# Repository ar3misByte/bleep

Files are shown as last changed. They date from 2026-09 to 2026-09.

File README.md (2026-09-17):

# Bleep

Worker safety monitoring for underground mine sites — a worker-worn ESP32 detects falls, prolonged inactivity, and environmental/vitals hazards, and a live dashboard surfaces alerts to site supervisors.

## Sensors on the worker unit

- **MPU6050** — 6-axis IMU: fall & impact detection, prolonged-inactivity detection
- **DHT11** — ambient temperature & humidity (heat-stress alerting)
- **BMP180** — barometric pressure
- **MQ-135** — toxic/air-quality gas
- **MQ-4** — combustible gas (methane/LPG) — the most safety-critical reading underground
- **MAX30102** — heart rate & an approximate SpO2 estimate
- **Soil moisture sensor** — floor-level water-ingress/flooding proxy
- **Physical SOS button** — manual worker-triggered distress

Every one of these feeds the same latched-alarm path (LED + buzzer on, dashboard shows a live DISTRESS event, cleared by pressing the SOS button again to acknowledge) — see [`dashboard_features.md`](./dashboard_features.md) for the full breakdown and current threshold values.

## Dashboard

[`index.html`](./index.html) is the dashboard — open it directly in a browser, or serve the repo with GitHub Pages. It's built with plain HTML/CSS/JS (no build step).

- **Worker roster cards** show live per-worker data wired to the real ESP32 hardware: motion energy, RSSI, temperature/humidity/pressure, gas readings, heart rate/SpO2, and soil moisture — the last four colored red once they cross the same danger threshold the firmware alarms on.
- **Event log** and **alert banner** cover every distress source (fall, SOS, inactivity, heat, gas, heart rate, SpO2, water ingress) generically, since `riskState`/`hazardType` are open strings, not a fixed enum.

See [`dashboard_features.md`](./dashboard_features.md) for the feature-by-feature status tracker (`LIVE` / `WIRED` / `PLANNED`) that the dashboard is kept in sync with.

### The three dashboard files

There are three HTML dashboards in this repo, not one — they're different snapshots, not alternatives to pick between at random:

- [`index.html`](./index.html) — the relay-server-connected dashboard described above. This is the one you actually serve from `server/app.py` to see real hardware.
- [`sensora_watch.html`](./sensora_watch.html) — the standalone, no-server "Sensora Watch" command dashboard (seven tabs: Overview, Workers, Alerts, Vitals & Gas, Mine Map, Reports, Admin) published as a Claude Artifact; see [`dashboard_features.md`](./dashboard_features.md) for what it does. Runs entirely on simulated data — open it directly in a browser.
- [`bleep_watch.html`](./bleep_watch.html) — the same command dashboard, rebranded ("Bleep Command" instead of "Sensora Watch") and with one addition: a **Live Data** tab that polls a wall node's own `/api/workers` endpoint directly (see "Second node pair" below) and shows the raw, unprocessed feed, so it's obvious where real hardware readings appear instead of them blending in with simulated worker cards. Configure the wall node address under Admin → Live Hardware.

## Connecting real hardware

The dashboard talks to hardware through a small relay server, not directly — the wall node is an HTTP **client**, the dashboard machine runs the HTTP **server**.

```
[worker wearable] --ESP-NOW--> [wall node ESP32] --WiFi/HTTP POST--> [server/app.py] --serves--> [index.html in your browser]
```

0. **Install the worker's Arduino libraries** (Library Manager): `Adafruit MPU6050`, `Adafruit Unified Sensor`, `DHT sensor library` (Adafruit), `Adafruit BMP085 Library` (covers BMP180), and `SparkFun MAX3010x Pulse and Proximity Sensor Library` (provides `MAX30105.h` and `heartRate.h`, used for the MAX30102). MQ-135, MQ-4, and the soil moisture sensor are plain `analogRead()` — no library needed.
1. **Put the wall node and your dashboard machine on the same WiFi network**, and find your machine's local IP (`ipconfig` on Windows, look for the WiFi adapter's IPv4 address — e.g. `192.168.1.50`).
2. **Edit [`firmware/wall_node.ino`](./firmware/wall_node.ino)**: set `WIFI_SSID`, `WIFI_PASSWORD`, and `DASHBOARD_URL` (`http://<your-ip>:5000/api/telemetry`) at the top, then flash it to the wall node's ESP32. It receives `WorkerPacket` structs over ESP-NOW from the wearable and forwards them as the telemetry JSON described in [`wifi_json_protocol.md`](./wifi_json_protocol.md).
3. **Run the relay server**:
   ```bash
   pip install -r server/requirements.txt
   python server/app.py
   ```
4. **Open the dashboard from the server, not the static file**: go to `http://<your-ip>:5000/` in a browser (on the same machine or anywhere else on the LAN). The page polls `/api/workers` and `/api/events` every 2 seconds — as soon as the wall node sends its first message, the page switches out of demo mode automatically: the worker roster, alert banner, and event log start showing real data, and the "Demo & Testing Controls" panel disables itself.

**Don't have wearable hardware yet?** Flash [`firmware/wearable_fall_simulator.ino`](./firmware/wearable_fall_simulator.ino) to a second ESP32 instead — it stands in for the wearable, sending STATUS packets every 2s and a simulated fall roughly every 45s (auto-recovering 15s later), so you can test the wall node → server → dashboard pipeline with no accelerometer involved.

**Why not just open `index.html` directly, or use the GitHub Pages copy?** Browsers block a page from fetching a plain-`http://` endpoint when the page itself was loaded over `https://` (GitHub Pages) or as a bare local file with no server behind it — the fetches to `/api/workers` fail silently and the page just stays in demo mode. Serving `index.html` from `server/app.py` (step 4) puts the page and the API on the same origin, which sidesteps this entirely. The hosted GitHub Pages copy is fine for showing the design, but it will never show live hardware data.

## Second node pair — tinyML anomaly detection ([`firmware/wall_n/`](./firmware/wall_n/), [`firmware/worker_n/`](./firmware/worker_n/))

[`firmware/wall_node.ino`](./firmware/wall_node.ino) and [`firmware/worker_node.ino`](./firmware/worker_node.ino) are left untouched. `wall_n.ino` and `worker_n.ino` are a **second, independent worker/wall pair** — not a replacement — that adds two things:

- **Its own local sensors on the wall node** — an MPU6050, BMP180, and DHT11 for room/wall-mounted environmental readings, plus an HC-SR04 ultrasonic sensor for distance/proximity (door, hazard boundary, or clearance sensing). See the pin map at the top of [`wall_n.ino`](./firmware/wall_n/wall_n.ino).
- **A tinyML anomaly-detection model on the worker node**, replacing hand-picked hazard thresholds with a small trained autoencoder (9 → 6 → 9) baked into `tinyml_model.h`. The model learns what a *normal* combination of the nine worker sensor readings looks like and flags a worker anomalous when the network can no longer reconstruct their current readings accurately — this naturally accounts for cross-sensor correlations (e.g. "high heart rate is only normal alongside high motion energy") that independent static thresholds can't express. Inference is plain float matrix math on-device, no TensorFlow Lite Micro runtime required.

`worker_n.ino`'s fall-detection and alarm logic is ported unchanged from a hand-tested standalone prototype — see the comment block at the top of [`worker_n.ino`](./firmware/worker_n/worker_n.ino) for exactly what carried over and what was intentionally dropped (e.g. there is no acknowledge button; the alarm stays latched until reset).

### Retraining the model ([`ml/train_tinyml_model.py`](./ml/train_tinyml_model.py))

`tinyml_model.h` (in both `firmware/wall_n/` and `firmware/worker_n/` — same generated file, kept in sync) is generated by `ml/train_tinyml_model.py`. There is no logged real-world sensor history for this project yet, so the script currently trains on **synthetic data** sampled from the plausible "normal" ranges already documented as static thresholds in `worker_node.ino` (`TEMP_DANGER_C`, `MQ135_DANGER_RAW`, `HR_DANGER_*`, etc.) plus typical sensor datasheet ranges. Treat this as a placeholder, not a substitute for real data — re-run the script against logged real sensor values as soon as they exist so the model learns the actual normal envelope for your site and workers. Run with `python ml/train_tinyml_model.py`; it has no dependency on the rest of the codebase beyond regenerating the header. See [`TinyML_Model_and_Datasets.md`](./TinyML_Model_and_Datasets.md) for the full writeup of the model architecture, training pipeline, and exactly how the synthetic dataset is built.

## PCB reference designs ([`kicad/`](./kicad/))

Vendored third-party reference material, not designs authored for this project — currently just Adafruit's own open-source [MPU6050 breakout PCB](https://www.adafruit.com/product/3886) (EagleCAD schematic/board files, CC BY-SA per Adafruit's license). Kept here as a starting reference for anyone laying out a custom PCB for the worker unit instead of prototyping on a breadboard.

## Design source

The `Main.dc.html` + `canvas.json` pair is the source for the same dashboard as an editable [Claude Design](https://claude.ai/design) canvas.

## Project docs

- [`Sensora_Hardware_Firmware_Spec.md`](./Sensora_Hardware_Firmware_Spec.md)
- [`wifi_json_protocol.md`](./wifi_json_protocol.md)
- [`sensora_telemetry.schema.json`](./sensora_telemetry.schema.json)
- [`sensora_architecture.md`](./sensora_architecture.md)
- [`Sensora_Feature_Build_Checklist.docx`](./Sensora_Feature_Build_Checklist.docx)
- [`Sensora_Novelty_Analysis.docx`](./Sensora_Novelty_Analysis.docx)
- [`Problem_Statement_SENSORA.pdf`](./Problem_Statement_SENSORA.pdf)

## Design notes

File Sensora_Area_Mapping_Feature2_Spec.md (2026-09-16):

# Feature 2 — Area Mapping with MPU6050 + HC-SR04 (gyro-swept ultrasonic scan)

**Supersedes the "proximity snapshot" scope-down in `dashboard-features.md` / `feature-build-checklist.md`.** Those docs parked full mapping because a continuous mechanical sweep needs a servo you may not have. This spec instead uses the **worker's own arm/body motion as the sweep mechanism** — MPU6050 gyro-integrated yaw tells you the angle, HC-SR04 tells you the distance at that angle, and the firmware fuses the two into a 2D point cloud. No servo required. This is genuinely buildable without new hardware if you already have both sensors, and it turns Feature 2 from a snapshot into an actual on-screen room/tunnel outline.

---

## 0. The core idea

A single ultrasonic sensor only measures distance along one ray. To get a *shape*, you need distance samples across a range of angles. Instead of motorizing the sensor, you have the person holding/wearing the unit **sweep it by hand** (like panning a flashlight across a room) while the firmware:

1. tracks the sensor's heading in real time by integrating the MPU6050's gyro Z-axis,
2. pings the HC-SR04 repeatedly during the sweep,
3. pairs each distance reading with the heading at that instant,
4. converts each (angle, distance) pair into an (x, y) point relative to the sweep's starting position,
5. streams the resulting point set to the dashboard, which draws it as a 2D outline.

This is a **relative, single-sweep scan**, not persistent SLAM — it answers "what does the space around the worker look like right now," which is exactly what Feature 2's brief was aiting at, and it's a much stronger demo than a single-ray snapshot.

---

## 1. Hardware (no new parts beyond what's already in the BOM)

| Component | Already in BOM? | Role here |
|---|---|---|
| ESP32 | Yes (worker or a dedicated scan node) | Compute, drives the sweep logic |
| MPU6050 | Yes (`hardware-firmware-spec.md` §1.1 — I²C, addr `0x68`) | Gyro Z-axis → yaw integration during the sweep |
| HC-SR04 | Yes, per `architecture-plan.md` §3.3 (used there for water level; you need a second unit, or repurpose logic — ultrasonic modules are ~$1–2, worth having two) | Distance ray at the current heading |

**Wiring (HC-SR04, in addition to the existing MPU6050 I²C bus from `hardware-firmware-spec.md` §1.3):**

| Signal | Suggested GPIO | Notes |
|---|---|---|
| TRIG | GPIO32 | Output, 10µs HIGH pulse to fire a ping |
| ECHO | GPIO33 | Input — **use a voltage divider (1kΩ/2kΩ) if your HC-SR04 is 5V-logic**, ESP32 GPIOs are not 5V tolerant |

Both GPIO32/33 are free ADC1-adjacent pins not used elsewhere in the worker pin map (§1.3 of `hardware-firmware-spec.md` uses 21/22/34/25/27/26/4/35) — confirm against your actual board before wiring.

If you're mounting this on a **separate dedicated scan unit** rather than the worker's own helmet (recommended — see §5), the same two sensors plus an ESP32 is the entire BOM; it doesn't need the gas/temp sensors or the buzzer.

---

## 2. Firmware: the sweep algorithm

### 2.1 Trigger a scan

Add a dedicated button (or repurpose a long-press on the existing SOS button if you want zero new parts) to start/stop a scan session. Keep sessions **short — 5 to 8 seconds** for a single sweep; this bounds gyro drift (§2.2) and keeps the data volume manageable over ESP-NOW.

```
on scanButtonPressed():
    if not scanning:
        startScan()   // zero the yaw integrator, clear the point buffer, set scanning = true
    else:
        endScan()     // stop sampling, package and send the accumulated points
```

### 2.2 Yaw tracking (gyro integration, with the drift caveat already flagged in your own docs)

This reuses exactly the pattern `architecture-plan.md` names for the (cut) GPS-replacement `yawDeg` field, and the complementary-filter idea already used for tilt in `hardware-firmware-spec.md` §7.3:

```cpp
// called every IMU sample (~50 Hz, non-blocking, per the main-loop discipline in §9 of the firmware spec)
void updateYaw(float gyroZ_degPerSec, float dt_s) {
    yawDeg += gyroZ_degPerSec * dt_s;
    // no magnetometer on hand -> no absolute heading correction.
    // Over a short (5-8s) sweep the drift is small enough to be visually
    // acceptable for a hackathon demo; DO NOT trust this for anything
    // longer-running or safety-critical. Label it as such on the dashboard
    // (see §4) exactly the way GPS-cut and simulated-data fields are labeled
    // elsewhere in this project.
}
```

Zero `yawDeg` at `startScan()` so every sweep is self-consistent even though absolute compass heading isn't available.

### 2.3 Ultrasonic sampling

```cpp
float pingDistanceCm() {
    digitalWrite(TRIG_PIN, LOW);  delayMicroseconds(2);
    digitalWrite(TRIG_PIN, HIGH); delayMicroseconds(10);
    digitalWrite(TRIG_PIN, LOW);
    unsigned long durationUs = pulseIn(ECHO_PIN, HIGH, 30000UL); // 30ms timeout ~= 5m range cap
    if (durationUs == 0) return -1;          // no echo / out of range -> discard sample
    float distanceCm = durationUs / 58.0f;
    if (distanceCm < 2 || distanceCm > 400) return -1;  // HC-SR04's real usable range
    return distanceCm;
}
```

**Important non-blocking note:** `pulseIn` blocks for up to its timeout (here 30ms). That's short enough not to meaningfully stall the mesh/heartbeat loop, but don't call it more often than every ~60ms (the HC-SR04 needs settling time between pings per its datasheet, matching the `MQ7`-style "don't take a shortcut on sensor timing" instruction already in `hardware-firmware-spec.md` §8) — schedule it the same way as the other periodic tasks in §9's `loop()` pattern:

```cpp
if (scanning && (now - lastPing >= SCAN_PING_INTERVAL_MS)) {   // config.h, default 100ms
    float d = pingDistanceCm();
    if (d > 0) {
        recordScanPoint(yawDeg, d);   // buffer the (angle, distance) pair
    }
    lastPing = now;
}
```

At 100ms per ping over a 6-second sweep, that's up to ~60 points — plenty for a recognizable outline, and small enough to fit in the packet budget below.

### 2.4 Polar → Cartesian conversion

Do this conversion **on the worker/scan node**, not the backend — it's cheap, and it means the packet carries directly plottable coordinates:

```cpp
struct ScanPoint { int16_t x_cm; int16_t y_cm; };  // fixed-point, matches the packet.h convention

ScanPoint toCartesian(float yawDeg, float distanceCm) {
    float rad = yawDeg * (PI / 180.0f);
    return { (int16_t)(distanceCm * cosf(rad)), (int16_t)(distanceCm * sinf(rad)) };
}
```

---

## 3. Wire format: extend `packet.h`, don't invent a parallel protocol

Per the note already in `dashboard-features.md` ("this is meant to extend the existing DISTRESS payload... not create a parallel envelope") and the versioned-payload pattern in `hardware-firmware-spec.md` §4, add a new `MsgType` rather than a new protocol:

```c
// packet.h additions
MSG_SCAN_CHUNK = 5,   // one chunk of a multi-packet area scan

typedef struct __attribute__((packed)) {
    uint8_t  scanId;        // increments per scan session, lets the gateway group chunks
    uint8_t  chunkIndex;    // 0-based
    uint8_t  chunkCount;    // total chunks in this scan, so the gateway knows when it's complete
    uint8_t  pointCount;    // points in THIS chunk
    int16_t  points[10][2]; // up to 10 (x_cm, y_cm) pairs per chunk
} ScanChunkPayload;         // 10*4 + 4 = 44 bytes, comfortably inside the 64-byte payload[] and the 250-byte ESP-NOW cap
```

A 60-point sweep needs 6 chunks of 10 points each — trivial over ESP-NOW, and it reuses the exact same anchor-relay/dedup path (§5, §6.2 of `hardware-firmware-spec.md`) every other packet type already uses, so nothing new is needed in the mesh layer.

**Gateway side:** buffer chunks by `scanId` as they arrive, and once `chunkCount` chunks are seen (or a timeout elapses — don't block waiting forever on a lost packet), assemble the full point list and emit one JSON message to the backend:

```json
{"msgType":"AREA_SCAN","srcId":103,"scanId":7,"originAnchorId":2,
 "points":[[120,45],[118,60],[95,88], ...], "pointCount":58, "rxAtMs":183820113}
```

---

## 4. Backend + dashboard

**Backend (`architecture-plan.md` §5 pattern):**
- New table: `area_scans(id, worker_id, ts, origin_anchor_id, points_json, is_partial)`.
- New MQTT topic: `sensora/scan/{nodeId}`.
- New WS diff type pushed to the dashboard when a scan completes.

**Dashboard — new panel, e.g. `AreaScanPanel`, following the design tokens already fixed in `dashboard-features.md`:**
- A simple 2D scatter/polygon plot (SVG, no charting library needed for point-count this small — same "hand-laid-out SVG beats a heavy graph library" reasoning already used for `NetworkTopology` in `architecture-plan.md` §6).
- Plot each point at `(x_cm, y_cm)` relative to a centered origin marker representing the worker.
- Connect consecutive points with a thin line in sweep order to suggest a wall outline (don't force a closed polygon — a partial sweep is an open arc, and closing it would misrepresent the room).
- **Label it clearly**, matching the project's existing honesty pattern (`SIMULATED DATA` flag, `SIMULATED MODEL` tag): something like **"Relative scan — gyro-only heading, may drift over the sweep"** near the panel, exactly the same treatment already used for the cut GPS/`yawDeg` field.
- If you also have the RSSI-based coarse worker position (`hardware-firmware-spec.md` §6.3) wired into the dashboard, you can offset the scan's origin to that estimated position on the main topology view — a nice-to-have, not required for the panel to be useful on its own.

---

## 5. Practical recommendation for the demo

Two ways to run this, pick based on time left:

1. **Handheld dedicated scan unit (recommended):** a second ESP32 + MPU6050 + HC-SR04 on a small breadboard/enclosure, separate from the worker's helmet. Someone holds it and slowly pans it in an arc in front of a judge-visible obstacle (a box, a chair leg) while pressing the scan button. This is the safest to rehearse because it's a standalone prop, not entangled with the worker's own fall/SOS firmware.
2. **Bundled into the worker node:** reuse the worker's existing MPU6050, add the HC-SR04, and trigger a scan either manually (extra button) or automatically on a DISTRESS event (the original intent noted in `dashboard-features.md`: "extend the existing DISTRESS payload"). More impressive narratively ("the system automatically scans the area around a fallen worker") but higher integration risk since it shares firmware/timing with the safety-critical path — only do this after option 1 works standalone, and don't let it block Feature 1.

Either way, rehearse the actual sweeping motion a few times before the demo — a jerky or too-fast sweep undersamples badly and produces a noisy scatter instead of a recognizable outline. A slow, steady ~90–180° arc over 5–8 seconds gives the cleanest result.

---

## 6. What to say if a judge asks about accuracy

> "This is a relative scan, not absolute mapping — the heading comes from gyro integration with no magnetometer, so it drifts over time. We bound that by keeping each sweep short, a few seconds, and treating each scan as a fresh, self-contained snapshot rather than accumulating drift over a long session. It's the same honesty pattern we use elsewhere in the project — labeled clearly on the dashboard rather than presented as more precise than it is."

This is consistent with, and reuses, the exact justification style already used for the cut GPS feature and the simulated flood model elsewhere in the project docs.

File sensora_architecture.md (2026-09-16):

# Sensora — System Architecture Plan

**Project:** Intelligent Worker Safety & Resilient Emergency Response System
**Prepared:** 15 Sep 2026 · Assumptions: 36–48h hackathon, 4–6 person team with role specialization, a few ESP32 boards + basic sensors already on hand (rest sourced/substituted below)
**Status:** Planning document — update as decisions change during the build

---

## 0. How to read this document

This is the architecture the team should build against, plus the reasoning behind each call and the places it's likely to break. Section 12 ("What a judge will challenge") is deliberately unflattering — read it before you pitch, not after a judge asks.

Everything below is scoped to **one coherent narrative**: an edge device assesses risk locally, a resilient mesh carries that risk assessment even as nodes die, and a command dashboard makes the whole chain visible in one glance. Every component earns its place by serving one of the five required demos. Nothing else gets built first.

---

## 1. System Overview

```
                         ┌───────────────────────────┐
                         │   COMMAND DASHBOARD (React) │
                         │  WebSocket live feed + REST │
                         └──────────────┬───────────────┘
                                        │ WS / HTTP
                         ┌──────────────┴───────────────┐
                         │   BACKEND (FastAPI + MQTT)    │
                         │  risk fusion · DB · APIs      │
                         └──────────────┬───────────────┘
                                        │ MQTT (paho)
                    ┌───────────────────┼────────────────────┐
                    │                                        │
         ┌──────────┴──────────┐                  ┌──────────┴──────────┐
         │  SCENARIO SIMULATOR  │                  │   GATEWAY NODE (ESP32) │
         │ (flood/scale/failure)│                  │  ESP-NOW ↔ USB-Serial │
         └───────────────────────┘                  └──────────┬──────────┘
                                                                │ ESP-NOW (2.4GHz)
                                        ┌───────────────────────┼───────────────────────┐
                                        │                       │                       │
                                 ┌──────┴──────┐        ┌───────┴──────┐        ┌───────┴──────┐
                                 │ HELMET NODE  │        │  RELAY NODE   │        │  ENV/FLOOD NODE│
                                 │ temp/gas/IMU │  ◄──►  │ (no sensors,  │  ◄──►  │ water level +  │
                                 │ /SOS/buzzer  │  mesh  │  forwards only)│        │ rainfall input │
                                 └──────────────┘        └───────────────┘        └────────────────┘
```

Two things make this "one system" instead of five demos glued together:

1. **Every physical node speaks the same packet format and joins the same mesh**, whether it's a helmet, a bare relay, or the flood sensor. The flood node's CRITICAL alert travels through exactly the same routing/failover logic as a worker's SOS.
2. **Real and simulated data enter the backend through the identical path** (MQTT topics). The flood scenario, a 14-worker site, and a mid-transmission node failure are all just different publishers on the same bus — this is the strongest architectural point to make to judges, because it proves the pipeline rather than the props.

---

## 2. Communication Layer — the central engineering decision

This is the feature judges will probe hardest, so the comparison has to be real, not decorative.

| | **ESP-NOW (custom mesh)** | **WiFi Mesh (painlessMesh)** | **LoRa (point-to-point / Meshtastic)** | **BLE / BLE Mesh** |
|---|---|---|---|---|
| Range (indoor, obstructed) | ~15–40m | ~15–40m | 500m–several km | ~5–15m |
| Throughput | Low, small packets (≤250B) | Higher (TCP over WiFi) | Very low (kbps) | Low |
| Power draw | Low–medium | Medium–high (WiFi radio stays up) | Very low (duty-cycled) | Low |
| Native multi-hop | No — you write it | Yes (library handles it) | No — point-to-multipoint only, mesh needs extra firmware/protocol | Only with BLE Mesh spec (complex) |
| Hardware cost/node | ESP32 only (~$4–6) | ESP32 only | ESP32 + LoRa module (~$8–15 extra) + antenna | ESP32 only |
| Implementation complexity | Medium (you own the routing logic, but that's also full control) | Low–medium (library does self-healing) | High (new radio stack, range testing, antenna tuning) | High for real mesh |
| **Demo control** (can you force a failure/reroute exactly on cue?) | **High** — deterministic, you wrote it | Medium — library's internal healing timing is a black box | Low in the time available | N/A here |
| Fit for "break a node → judges watch it reroute" | **Best** | Good, less predictable | Would need too much new firmware to trust live | Not viable in this window |

**Recommendation: ESP-NOW as the radio, with a small custom application-layer routing protocol on top.**

Why not the "better" options:
- **WiFi mesh (painlessMesh)** is a legitimate alternative and less code to write, but you're trading control for convenience — its self-healing timing isn't yours to tune, which is risky when the entire Demo 3 depends on the reroute happening within a judge's attention span. If your team already knows painlessMesh well, it's an acceptable swap; otherwise don't learn a new library and a new protocol in the same 48 hours.
- **LoRa/Meshtastic** is the "sexiest" answer and genuinely fits a disaster narrative better (km-scale range), but it adds a second hardware type, an unfamiliar stack, and antenna/range testing you won't have time to debug if it goes wrong the night before. Flag it explicitly to the team and judges as **"the deployment-scale answer, out of scope for this prototype"** — that's an honest, technically credible statement, not a cop-out.
- **BLE mesh** is out — short range and the mesh spec is too heavy to implement correctly in this window.

### 2.1 Routing protocol ("SensoraMesh" — hackathon-scoped, hybrid)

This mirrors the idea behind Collection Tree Protocol (a well-known wireless-sensor-network pattern) for normal traffic, plus **flooding for anything safety-critical**, because flooding is trivially self-healing — it doesn't depend on any single path being correct, which is exactly the property you want on stage.

- Every node broadcasts a `HEARTBEAT` every 2–3s: `{nodeID, role, hopCountToGateway, battery, seq}`.
- Each node keeps a small neighbor table (`neighborID, RSSI, lastSeen, theirHopCount`) and computes `myHopCount = min(neighbor hopCount) + 1`, picking the neighbor with the lowest hop count (tie-break: strongest RSSI) as `bestNextHop`. This is a simple distance-vector/gradient routing toward the gateway.
- **Failure detection:** if no heartbeat from the current `bestNextHop` for 3 missed intervals (~9s), mark it stale and recompute from the remaining table. This 9s window is your reroute demo's visible "thinking" pause — don't try to make it instant, a visible-but-quick recovery actually reads better to judges than something so fast it looks scripted.
- **Normal telemetry** (NORMAL/WARNING state, low priority): unicast hop-by-hop via `bestNextHop`. Cheap, low airtime.
- **Emergency traffic** (CRITICAL/SOS, priority=1): **constrained flood** — broadcast to all neighbors, each relay forwards once (dedup cache keyed by `{srcID, seq}`, TTL-expired after a few seconds), hop-limited (e.g. TTL=8). This guarantees delivery via multiple simultaneous paths without waiting for route recomputation — the actual mechanism behind Demo 3.
- Gateway node bridges the mesh to the backend over **USB serial** (not WiFi) — this keeps the last hop deterministic during the demo (no dependency on venue WiFi/hotspot flakiness). The mesh itself is what's "resilient"; the laptop tether is a deliberate, disclosed simplification.

**If a judge says "isn't flooding just cheating instead of real routing?"** — answer: for safety-critical low-node-count networks, controlled flooding (TTL + dedup) is a legitimate, widely-used resilience pattern (it's the reliability mechanism behind Bluetooth Mesh and many disaster-relief mesh designs), traded deliberately against airtime efficiency. You're using the efficient path (distance-vector) for routine data and the robust path (flood) only for the traffic where guaranteed delivery matters more than efficiency — that's the "priority-aware" differentiator, not an accident.

### 2.2 Packet format

Fixed binary header to stay inside ESP-NOW's ~250-byte payload:

```
byte 0    : version
byte 1    : msgType        (0=HEARTBEAT, 1=TELEMETRY, 2=EMERGENCY, 3=ENV, 4=ACK)
byte 2    : srcID          (1-byte node address, fine for a demo-scale network)
bytes 3-4 : seq            (uint16, per-source sequence number — used for dedup + replay rejection)
byte 5    : ttl            (hop limit, decremented per forward)
byte 6    : hopCount       (hops traveled so far, for routing table math)
byte 7    : priority       (0=normal, 1=emergency)
byte 8    : payloadLen
bytes 9-9+len : payload    (type-specific, see below)
last 2 bytes : CRC16       (integrity check)
```

- `TELEMETRY` payload: `tempC (int16), gasRaw (uint16), motionFlag (uint8), batteryPct (uint8)`
- `EMERGENCY` payload: `hazardType (uint8 enum), severity (uint8 enum), tempC, gasRaw, motionFlag, workerID, zoneID` (no live GPS — see §3.4)
- `ENV` payload: `waterLevelCm (uint16), rainfallIntensity (uint16), rateOfRiseCmPerMin (int16), isSimulatedFlag (uint8)`

The gateway decodes this into JSON before it ever reaches the backend, so nothing downstream needs to know about the wire format.

### 2.3 Security (address this honestly, don't ignore it)

Full mesh security (per-hop TLS, key rotation) is out of scope for 48 hours. What's cheap and worth doing, and what to say about the rest:

- **Already free:** the `seq` field doubles as replay/duplicate protection — reject packets with a `seq` at or below the last seen for that `srcID`.
- **Cheap to add:** a pre-shared-key truncated HMAC (e.g. HMAC-SHA256 truncated to 1–2 bytes) appended per packet, keyed per-node, to stop trivial spoofed-SOS packets. A few lines of firmware, a real talking point.
- **Explicitly out of scope, say so on stage:** encrypted payloads, key rotation/provisioning, and TLS on the mesh hop. State the real-world mitigation (per-node provisioned keys, DTLS-style handshake) as "how this would harden for deployment" rather than leaving it unaddressed — judges respect a named gap far more than a silent one.
- Dashboard/API layer: basic auth token on REST + WS in this prototype; note that a deployable version needs proper auth/roles for supervisors vs. read-only viewers.

---

## 3. Hardware — per-node bill of materials

You said you have **a few ESP32 boards + basic sensors already** — treat "basic sensors" as DHT-family temp + maybe an MPU6050, and assume gas and water-level sensors still need sourcing (cheap, ~$2–5 each, widely stocked). Confirm this against what's actually in the box before hour 0.

### 3.1 Helmet / Worker Node
| Sensor | Purpose | Notes / risk |
|---|---|---|
| ESP32 dev board | Compute + radio | — |
| MPU6050 (I2C accel+gyro) | Fall/impact + abnormal-motion detection | Cheap, reliable, well-documented — lowest-risk sensor here |
| MQ-2 or MQ-135 (analog) | Gas/smoke presence | **Flag:** these need 24–48h burn-in for a stable baseline and are not calibrated to ppm. Detect *relative deviation from a power-on baseline*, not absolute concentration, and say so explicitly on the dashboard/pitch. Don't claim industrial-grade gas detection. |
| DHT22 or similar | Ambient temperature | Cheap, adequate for "excessive heat" demo |
| Push button (SOS) | Explicit emergency override | Debounce in firmware, use interrupt not polling |
| Buzzer + status LED (or small SSD1306 OLED if time allows) | Local feedback of NORMAL/WARNING/CRITICAL/SOS **even with zero connectivity** | This is what proves "risk assessed locally" — don't skip it for the mesh/dashboard and forget the helmet needs its own visible state |
| LiPo + TP4056 charge module + voltage divider into ADC | Power + battery % | Needed for the "Battery" field the brief explicitly asks the dashboard to show |
| GPS (NEO-6M) | Location | **Cut for the live demo unless you'll be outdoors with clear sky** — cold-start fix can take 30s–minutes and won't reliably lock indoors. Use fixed **Zone labels (Zone 1/2/3)** set per node instead; mention GPS as a designed-in, deployment-time capability. |

Rough power budget: ESP32 active + ESP-NOW ≈ 120–180mA, sensors add ~20–50mA → a 2000mAh LiPo gives roughly 8–12h continuous. Good enough to state a number if asked; don't over-promise beyond that.

### 3.2 Relay Node
Just an ESP32 running the mesh firmware in `RELAY` role, no sensors — this is the node you'll physically power off mid-demo. Add a single status LED so judges can see it die and later see a different relay light up as the new path.

### 3.3 Environmental / Flood Node
| Sensor | Purpose | Notes |
|---|---|---|
| Ultrasonic (HC-SR04) pointed down into a water container/tube | **Real, physical** water level measurement | Genuinely real sensor data — good to have at least one real physical signal in the flood demo, not everything simulated |
| Potentiometer (or a slider control) | Presenter-controlled **simulated** rainfall intensity | Transparent, honestly-labeled simulation the presenter can visibly turn up live — this satisfies "clearly label simulated data" *while still being an interactive physical demo*, better than a screen-only slider |
| ESP32 | Compute + radio | Same firmware family as other nodes, `ENV` role |

This hybrid (real water level + presenter-driven simulated rainfall) is a deliberate design choice: it's honest about what's simulated while still giving you something tangible to physically manipulate on stage, which reads much better than "trust me, the number changed in software."

### 3.4 Gateway Node
ESP32 in `GATEWAY` role, connected via **USB serial** to the laptop/Pi running the backend (see §2.1 for why serial over WiFi at this one hop). No sensors.

---

## 4. Risk Engine — edge (deterministic) + backend (ML)

Two layers, deliberately different in character:

### 4.1 Edge (on each helmet ESP32, C/C++, must be 100% reliable)

A small, explainable, weighted rule engine — not ML, and that's correct here, not a shortcut:

```
if SOS pressed:                          → SOS         (always overrides everything)
if fall detected AND no motion for Ns:   → CRITICAL    (impact spike, then near-zero variance)
score = w1*tempAnomaly + w2*gasDeviation + w3*motionAnomaly
if score > highThreshold:                → CRITICAL
elif score > medThreshold:                → WARNING
else:                                      → NORMAL
```

This runs and drives the local buzzer/LED even with **zero radio connectivity** — that's the point: risk assessment is local, communication is a separate, best-effort layer on top. Keep this deterministic; a safety-critical local state should not depend on a model that could behave unpredictably on stage.

### 4.2 Backend (Python/scikit-learn) — where "AI" is actually earned

- **Flood risk (primary ML component):** engineer features from the env-node stream — current water level, rate-of-rise over 1/5/15-minute rolling windows, rainfall intensity, accumulated rainfall — and train a small classifier (Gradient Boosted Trees or even a well-tuned Logistic/Ordinal Regression) on a **clearly-labeled simulated dataset** of many synthetic monsoon-style episodes, outputting NORMAL → WATCH → WARNING → CRITICAL with hysteresis (don't flip state on a single noisy sample). This is the strongest, most defensible ML claim in the system because the brief explicitly asks for exactly this multi-signal short-horizon estimate, and a trained model demonstrably beats a bare threshold on the synthetic data (bring that comparison chart to the demo).
- **Cross-worker anomaly detection (secondary, if time allows):** a simple z-score / Isolation Forest over the *current fleet's* readings — flags "multiple workers simultaneously showing elevated readings" as a site-wide pattern distinct from one worker's local spike. Cheap to build, genuinely differentiated, and a good example of fusion that a single edge device structurally cannot do on its own.
- **Do not** reach for deep learning anywhere in this system — every signal here is low-dimensional and well-served by classical ML; a judge asking "why not a neural net" should get "because it wouldn't outperform this on this data, and it would cost us interpretability we need for a safety system" as a confident answer, not a dodge.

Label every simulated-data-driven output on the dashboard, literally, as the brief requires (e.g. a small "SIMULATED MODEL" tag next to the flood risk badge).

---

## 5. Backend

**Stack:** FastAPI (Python) + MQTT (Mosquitto broker, `paho-mqtt` client) + SQLite (via SQLAlchemy) + WebSocket for the dashboard feed.

Why MQTT specifically, not just an in-process queue: it decouples ingestion from processing, it's the stack a judge will recognize as the "correct" IoT choice, and — most importantly — **it lets the simulator and the real gateway be two publishers on the identical topics**, so simulated flood/scale/failure scenarios flow through the exact same risk-engine and dashboard code path as real hardware. That architectural fact is worth stating out loud in the pitch.

**Topics:**
```
sensora/telemetry/{nodeId}
sensora/emergency/{nodeId}
sensora/env/{nodeId}
sensora/network/{nodeId}/heartbeat
sensora/network/topology        (backend-published, derived from heartbeats)
```

**Data flow:** Gateway (serial) → small Python reader script → publishes JSON to MQTT → FastAPI backend subscribes → runs risk fusion (§4.2) → writes to DB → pushes diffs to connected dashboards over WebSocket, and republishes derived events (state changes, reroutes, alerts) back onto MQTT for anything else that wants them (e.g. the simulator, for closed-loop scenario scripting).

**Database (SQLite is the right call here — zero ops, plenty for demo scale):**

```
workers(worker_id, name, role, last_seen, battery, status, zone, node_id)
nodes(node_id, role, last_seen, battery, rssi_to_next_hop, next_hop_id, hop_count, status)
telemetry(id, node_id, ts, temp, gas, motion_flag, battery, raw_json)
events(id, ts, node_id, worker_id, event_type, severity, hazard_type, message, acknowledged)
network_events(id, ts, event_type[NODE_UP|NODE_DOWN|ROUTE_CHANGE], node_id, detail_json)
env_readings(id, node_id, ts, rainfall_intensity, water_level_cm, rate_of_rise, risk_state, is_simulated)
```

**API surface:**
- `GET /workers`, `GET /nodes`, `GET /events`, `GET /env/latest` — initial dashboard load
- `WS /ws/live` — streaming diffs (worker status, network topology, events, env risk)
- `POST /events/{id}/ack` — supervisor acknowledgment (the brief's user-flow step 8)

Security for this layer: token-based auth on the REST/WS endpoints in the prototype; note real deployment needs per-role auth (supervisor vs. viewer) and TLS — same "named gap, stated mitigation" treatment as §2.3.

---

## 6. Dashboard

React + Vite (skip Next.js unless the frontend person already knows it well — it buys nothing extra at this scale and costs setup time) + native WebSocket client.

Component breakdown, matching the brief's mockup directly:

- **StatusBar** (always visible, top): workers online/total, network health badge, active emergency count, environmental risk badge — the "understand this in 3 seconds" requirement lives here.
- **WorkerPanel**: one row/card per worker — status **shape + color + text label** (not color alone, per the accessibility requirement), battery, zone, connectivity, last update.
- **NetworkTopology**: small fixed-layout node graph (5–8 nodes at demo scale — don't reach for a force-directed graph library, a hand-laid-out SVG mirroring the physical table arrangement of your boards is easier to get right and reads better to judges who can look at the table and the screen together). Node fill = status, edge = current `bestNextHop` link, redraw on `ROUTE_CHANGE` events.
- **EnvironmentalPanel**: water level + rainfall + rate-of-rise as simple gauges/sparklines, risk badge (NORMAL/WATCH/WARNING/CRITICAL), explicit "SIMULATED" tag on the rainfall input.
- **EventTimeline**: scrolling log, formatted exactly like the brief's example (`HH:MM:SS — event text`).
- **AlertBanner**: full-width, dominant, appears only when a CRITICAL/SOS event is active — this is the "ACTIVE ALERT" hero block from the mockup, and it should visually out-rank everything else on the page when present.

Visual language: dark control-room background, status colors (green/amber/orange/red) always paired with an icon + text label, minimal decoration — the brief is explicit that this should look like an operations center, not a student IoT dashboard. When you get to actually building this screen, load the `dataviz` and `artifact-design` skills for the color/accessibility/layout specifics rather than improvising them.

---

## 7. Build Plan — 36–48h, 4–6 people

Assumes specialization: 1–2 embedded/hardware, 1 comms/firmware, 1–2 backend, 1 frontend (adjust to your actual split, but keep at least one person owning comms full-time — it's the highest-risk piece).

**Phase 0 (hours 0–3) — de-risk, don't build features yet**
Flash a blink/hello-world to *every* ESP32 board you plan to use. Confirm Arduino/PlatformIO toolchain, library versions (ESP-NOW examples, MPU6050 lib) on every laptop that needs them. This phase's only job is finding out now which board or cable is dead, not at hour 40.

**Phase 1 (hours 3–16) — parallel tracks, no cross-dependencies yet**
- *Embedded:* single helmet node reading all sensors + local rule engine + local buzzer/LED state. Demo-1-critical-path, and it works standalone with zero network.
- *Comms:* two boards exchanging heartbeats, neighbor table, hop-count computation. Get failure-detection timing tuned in isolation before adding more nodes.
- *Backend/Frontend:* build the FastAPI + MQTT skeleton and the React dashboard shell **against a fake data generator**, so this track is never blocked waiting on hardware. This generator becomes your permanent simulator (§4.2, §5) — not throwaway code.

**Phase 2 (hours 16–28) — integration checkpoint 1**
Merge sensors + rule engine + comms into full helmet firmware. Extend the mesh to 3+ physical nodes (helmet, relay, gateway). Swap the backend's fake generator for the real gateway feed. Verify Demo 1 (hazard escalation) and Demo 2 (SOS) end-to-end with real hardware.

**Phase 3 (hours 28–38) — integration checkpoint 2**
Implement and rehearse the kill-a-relay reroute (Demo 3) — know in advance exactly which physical node gets unplugged and when. Bring up the flood/env node and wire its output into the dashboard (Demo 4).

**Phase 4 (hours 38–end minus buffer) — polish + rehearse**
Dashboard visual pass against §6 and the brief's mockup (Demo 5). Full run-through of the single narrative end-to-end, multiple times, with different people driving.

**Reserve the final 10–15% of total time purely for integration bugs and rehearsal.** This is the single most common reason hackathon demos fail — teams build until the last hour and never rehearse the failure-and-reroute moment, which is exactly the demo with the most moving parts. If Phase 4 is running short, cut dashboard polish before you cut rehearsal time.

**Fallback plan:** record a clean run of the full demo (screen capture + phone video of the physical rig) by the start of Phase 4, in case live hardware misbehaves in front of judges. Never present this as the primary demo, but have it ready.

---

## 8. What a judge will challenge — say this before they ask

- **"Your gas sensor readings aren't real ppm values."** Correct — MQ-series sensors need days of burn-in for calibrated absolute readings. We detect deviation from a power-on baseline, and we say so on the dashboard. This is a deliberate, disclosed scope cut, not an oversight.
- **"GPS isn't live."** Correct, and intentionally cut — GPS cold-start doesn't reliably lock indoors within a demo window. We use fixed zone labels; GPS is a designed-in field the firmware/packet already supports for outdoor deployment.
- **"Isn't flooding just avoiding real routing?"** No — it's a deliberate reliability/efficiency trade-off: distance-vector for routine telemetry, flood-with-TTL for anything safety-critical, because guaranteed delivery matters more than airtime for an SOS. This is a known pattern in disaster-relief and sensor-network mesh design, not an ad hoc shortcut.
- **"Your flood model is trained on data you made up."** Correct, and labeled as such live on the dashboard. It proves the pipeline — real sensor → features → model → calibrated alert → resilient transmission — works end to end; it does not claim validated flood science. That's explicitly the brief's own instruction for this feature.
- **"Why not just use LoRaWAN/Meshtastic/existing infrastructure?"** Those solve long-range radio connectivity, not the vertical integration this system provides: multi-sensor fusion at the edge, a safety state computed locally with zero connectivity, and priority-aware routing tailored to an emergency packet format. The differentiator is the whole chain, not the radio.
- **"Does this scale past your demo's node count?"** Not as built — 1-byte node addressing, an in-memory backend state, and SQLite cap out well before hundreds of nodes. That's a known, named ceiling; a real deployment would move to a proper mesh routing protocol (e.g. something in the B.A.T.M.A.N./Zigbee family), a real broker cluster, and a production database. Say this proactively; it reads as engineering maturity, not weakness.
- **"What's the actual battery life?"** ~8–12 hours on a 2000mAh LiPo at the current draw estimate (§3.1) — enough to state with confidence, not enough to over-promise a multi-day deployment without a bigger battery or duty-cycling the radio.

---

## 9. Open items to confirm before Phase 0

1. Exact contents of the "basic sensors" already on hand — confirm against §3 before assuming what still needs sourcing (gas sensor and water-level sensor are the most likely gaps).
2. Confirm venue realities: will you have table space to physically lay out helmet/relay/env/gateway nodes in a fixed arrangement matching the on-screen topology? This materially simplifies §6's topology panel.
3. Decide now who owns the comms/firmware track full-time — of everything in this document, it's the piece with the least forgiving debugging loop, and it should not be a shared/rotating responsibility.

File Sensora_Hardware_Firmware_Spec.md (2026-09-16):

# Sensora — Hardware & Firmware Implementation Specification
### Mine Deployment: Wall-Mounted Anchor Backbone + Worker Sensor Node

**Audience:** this document is written to be handed to another AI coding agent (or a human firmware engineer) with no other context, and used as the sole spec for implementing the embedded firmware. Where a decision is left open, it says so explicitly and names the config constant that must expose it — do not silently hardcode a guess.

**Relationship to earlier project docs:** `architecture-plan.md` (in this project) covers the backend, dashboard, and ML layers, and a *generic* flat-mesh topology. This document **supersedes** that doc's §2 (Communication Layer) and §3 (Hardware BOM) for the topology now confirmed: fixed wall-mounted anchor nodes forming the network backbone, plus mobile worker nodes that are sensor sources but not relays. Everything downstream of the gateway (MQTT topics, DB schema, dashboard) still applies unchanged — only the packet format is extended (§4) to carry the new fields this topology needs.

**Deliberate mandate — read this before writing any code:** the team already knows of other implementations using the same sensor types (temperature, humidity, MPU6050, atmospheric pressure, air quality). The requirement here is that **the underlying logic must be different, not just the wiring.** §7, §8, and §9 exist specifically to replace the "read a sensor, compare to a fixed threshold" pattern used elsewhere with adaptive, justified algorithms. §14 is a checklist of exactly what to avoid re-implementing. Treat that checklist as a hard constraint, not a suggestion.

---

## 0. System Topology

```
   (surface / mine entrance)                                    (mine face, deeper in)
        ┌──────────┐        ┌──────────┐        ┌──────────┐        ┌──────────┐
        │ ANCHOR 1  │◄──────►│ ANCHOR 2  │◄──────►│ ANCHOR 3  │◄──────►│ ANCHOR N  │  ...
        │ =GATEWAY  │        │           │        │           │        │           │
        │ (USB→PC)  │        │           │        │           │        │           │
        └────┬─────┘        └────┬─────┘        └────┬─────┘        └────┬─────┘
             │  ▲                 │  ▲                 │  ▲                 │  ▲
             │  │ ESP-NOW         │  │                 │  │                 │  │
             ▼  │ (worker→        ▼  │                 ▼  │                 ▼  │
        ┌──────────┐        ┌──────────┐        ┌──────────┐        ┌──────────┐
        │ WORKER A  │        │ WORKER B  │        │  (empty)  │        │ WORKER C  │
        │ (mobile)  │        │ (mobile)  │        │           │        │ (mobile)  │
        └──────────┘        └──────────┘        └──────────┘        └──────────┘
```

Two roles only. This is a deliberate simplification from a fully general mesh, and it matches how real fixed-reader / mobile-tag industrial tracking systems are built underground — fixed infrastructure is reliable and gets the hard job (multi-hop relaying); mobile nodes get the simple job (talk to whichever fixed node is closest).

- **ANCHOR** (`ROLE_ANCHOR`): wall-mounted, fixed position, mains/battery-buffered, no sensors required. Forms the backbone chain by relaying to its neighbors. One specific anchor (physically the one nearest the mine entrance / nearest existing connectivity) is additionally flagged `IS_GATEWAY` and bridges to the surface backend over USB serial. Anchors are installed **in physical order** at regular intervals (e.g. every 40–60 m) and are given sequential IDs in that order — the ID sequence *is* the position reference (§6).
- **WORKER** (`ROLE_WORKER`): worn by a person, mobile, carries the full sensor set (§1). A worker is a **leaf node**: it only ever talks to whichever anchor it currently hears best. It never relays another worker's traffic. This is what makes the system robust to workers moving in and out of range — you're only ever depending on the fixed backbone, not on other people also being nearby.

---

## 1. Bill of Materials

### 1.1 WORKER node

| Component | Part | Interface | Purpose |
|---|---|---|---|
| MCU | ESP32 dev board (WROOM-32, 30- or 38-pin) | — | Compute + ESP-NOW radio |
| Temp / humidity / pressure | **BME280** (not separate DHT22 + barometer — one I²C chip covers all three, faster sampling, and is itself a departure from the DHT22-based designs this needs to differ from) | I²C, addr `0x76` or `0x77` (check module's SDO strap) | §7 fusion inputs; pressure specifically for **rate-of-change**, not absolute value (§7.2) |
| Motion | **MPU6050** (accel + gyro) | I²C, addr `0x68` (or `0x69` if `AD0` strapped high) | Fall detection + tilt/orientation (§7.3) |
| Gas | **MQ-7** (CO) as primary — see the hardware-honesty note below | Analog (ADC1 channel) + 1 GPIO for heater control (§8) | The acutely dangerous gas underground is carbon monoxide (blasting, diesel equipment, fire), not generic "air quality" |
| SOS | Momentary push button, normally-open, to GND | GPIO w/ internal pull-up, interrupt-driven | Hard override, always wins (§7.4) |
| Local feedback | Piezo buzzer (GPIO + transistor if >20mA) **and** a status LED — prefer a single WS2812 addressable RGB LED on one GPIO over three discrete LEDs, fewer pins, more states | GPIO (buzzer), GPIO (LED data) | Must show state with **zero network connectivity** (§7.5) |
| Power | 2000–3000 mAh LiPo + TP4056 charge module + a 100kΩ/100kΩ divider into an ADC pin (battery is well above 3.3V logic max, divider is mandatory, do not connect raw cell voltage to a GPIO/ADC) | ADC1 channel | Battery % telemetry |

**Hardware-honesty note on "air quality":** if the team's "air quality" sensor on hand is a generic MQ-135 (broad VOC/CO2-ish index, uncalibrated), it is not a good proxy for the two gases that actually kill people underground: **carbon monoxide** and **methane**. Wire and read whatever sensor is physically available (the firmware in §7 is written generically against "gas channel," swap the calibration constants in `config.h`), but flag to the team in the pitch that a real deployment needs a CO-specific sensor (MQ-7) at minimum, and methane (MQ-4) as a second channel if the mine has blasting/gas pockets. Don't let "air quality" imply broader safety coverage than the actual sensor provides.

### 1.2 ANCHOR node

| Component | Part | Interface | Purpose |
|---|---|---|---|
| MCU | ESP32 dev board | — | Compute + ESP-NOW radio |
| Status LED | Single LED (or WS2812) | GPIO | Visual "alive / relaying / gateway" indicator for the demo — this is the node someone will physically power off on stage |
| Power | USB / mains adapter, or LiPo + charge module if no wall power at that point in the tunnel | — | Anchors are meant to be always-on infrastructure |
| Gateway variant only | USB cable to the laptop/Pi running the backend | UART (native USB-serial on most ESP32 dev boards) | Bridges mesh → backend (§10) |

Anchors carry **no sensors** in this spec. If the team wants an anchor to double as the flood/environmental node from `architecture-plan.md` §3.3, that is an additive role flag (`ROLE_ANCHOR | ROLE_ENV`) — out of scope for this document, mention it back to the team rather than improvising it.

### 1.3 Pin map (WORKER, ESP32 WROOM-32 30-pin reference — renumber for the exact board on hand)

| Signal | GPIO | Notes |
|---|---|---|
| I²C SDA (BME280 + MPU6050 shared bus) | GPIO21 | Both chips on one bus; addresses differ, no conflict |
| I²C SCL | GPIO22 | 4.7kΩ pull-ups to 3.3V if not already on the breakout modules |
| MQ-7 analog out | GPIO34 (ADC1_CH6, input-only pin, correct choice for analog) | Never use ADC2 pins if Wi-Fi/ESP-NOW is active — ADC2 conflicts with the radio driver |
| MQ-7 heater control | GPIO25 (PWM-capable) | Through a logic-level MOSFET (e.g. 2N7000), not driven directly (§8) |
| SOS button | GPIO27, `INPUT_PULLUP`, interrupt on `FALLING` | Debounce in software (§9), not just hardware RC, so timing is inspectable/loggable |
| Buzzer | GPIO26 (via transistor if current draw requires it) | PWM tone generation |
| Status LED (WS2812) | GPIO4 | Single-wire addressable — one pin, many colors/states |
| Battery ADC | GPIO35 (ADC1_CH7, input-only) | Through the voltage divider — never raw cell voltage |

**Do not use GPIO 6–11** (connected to the onboard SPI flash) or GPIO 0/2/15 without checking the specific board's strapping behavior at boot.

---

## 2. Firmware File Structure (both node types share this skeleton)

Both ANCHOR and WORKER firmware should be **one shared codebase** compiled with a role flag, not two divergent sketches — this is what makes "kill the anchor, worker keeps working" a property of the design rather than luck.

```
/firmware
  /include
    config.h          # every tunable constant, every pin, ROLE_* defines — nothing tunable lives outside this file
    packet.h          # wire-format structs (§4) — shared verbatim by both roles
  /src
    main.cpp          # setup()/loop(), role dispatch
    mesh.cpp / .h      # ESP-NOW init, peer management, routing table, heartbeat, failure detection (§5, §6)
    sensors.cpp / .h   # BME280 / MPU6050 / MQ-7 acquisition (§8) — WORKER only, compiled out for ANCHOR
    risk_engine.cpp / .h  # adaptive baseline + fusion + hysteresis + overrides (§7) — WORKER only
    localization.cpp / .h # RSSI-based position estimate (§6.3) — WORKER only
    gateway_bridge.cpp / .h # serial JSON bridge (§10) — GATEWAY build only
    ui.cpp / .h        # LED/buzzer state rendering (§7.5) — WORKER only (ANCHOR just needs a simple "alive" blink)
```

`config.h` must define, at minimum: `NODE_ROLE` (`ROLE_ANCHOR` / `ROLE_WORKER`), `IS_GATEWAY` (bool, anchors only), `NODE_ID` (uint8), `ANCHOR_POSITION_M` (float, anchors only), `WIFI_CHANNEL` (must match across every device on site — pick one, default `6`), plus every threshold/weight named in §7 and §8. **No magic numbers in the `.cpp` files** — if a value affects behavior, it lives in `config.h` with a comment explaining what it controls.

---

## 3. ESP-NOW API note (check before coding)

Arduino-ESP32 core has two coexisting APIs:

1. **Raw ESP-IDF C API** (`esp_now.h`: `esp_now_init()`, `esp_now_register_recv_cb()`, `esp_now_register_send_cb()`, `esp_now_add_peer()`, `esp_now_send()`) — stable across core 2.x and 3.x, the most widely documented, and what this spec's pseudocode assumes.
2. A newer **class-based wrapper** (`ESP_NOW`, `ESP_NOW_Peer` classes) shipped in recent core 3.x — object-oriented, less example coverage as of this writing.

**Use the raw C API (option 1)** unless the team's installed core version doesn't expose it — it's more portable across board packages and every ESP-NOW tutorial the team will find while debugging uses it. Confirm the installed `arduino-esp32` core version on every laptop before Phase 0 (per the build-plan doc) — a version mismatch across team laptops is a common, avoidable source of "works on my machine."

ESP-NOW payload cap is **250 bytes** on classic ESP32 (WROOM-32) — the packet format in §4 is sized to fit with headroom. All nodes must be on the **same Wi-Fi channel** (`config.h: WIFI_CHANNEL`) — ESP-NOW does not negotiate this for you.

---

## 4. Wire Packet Format

```c
// packet.h — shared verbatim by ANCHOR and WORKER builds
typedef enum : uint8_t {
  ROLE_ANCHOR = 0,
  ROLE_WORKER = 1,
} NodeRole;

typedef enum : uint8_t {
  MSG_ANCHOR_BEACON = 0,   // anchor -> everyone in range, periodic
  MSG_TELEMETRY      = 1,  // worker -> its chosen anchor, routine
  MSG_EMERGENCY       = 2, // worker -> its chosen anchor (unicast attempt) or all anchors (broadcast fallback)
  MSG_ANCHOR_RELAY    = 3, // anchor -> anchor, carries a forwarded TELEMETRY or EMERGENCY payload toward the gateway
  MSG_ACK             = 4,
} MsgType;

typedef struct __attribute__((packed)) {
  uint8_t  version;        // = 1
  uint8_t  msgType;        // MsgType
  uint8_t  srcId;          // original sender's NODE_ID (worker or anchor)
  uint8_t  srcRole;        // NodeRole of the ORIGINAL sender (unchanged as it's relayed)
  uint16_t seq;            // per-source sequence number — dedup + replay rejection
  uint8_t  ttl;            // hop budget, decremented by each relaying anchor
  uint8_t  hopCount;       // hops traveled so far
  uint8_t  priority;       // 0 = normal, 1 = emergency
  uint8_t  payloadLen;
  uint8_t  payload[64];    // interpreted per msgType, see below — pad unused bytes with 0
} MeshPacket;              // sizeof <= 74 bytes, comfortably under the 250-byte ESP-NOW cap

// payload for MSG_ANCHOR_BEACON:
typedef struct __attribute__((packed)) {
  float    positionM;         // this anchor's surveyed distance from entrance, meters
  uint8_t  hopCountToGateway; // 0 for the gateway anchor itself
  uint8_t  battery;           // 0-100, or 0xFF if mains-powered (no battery)
} BeaconPayload;

// payload for MSG_TELEMETRY:
typedef struct __attribute__((packed)) {
  int16_t  tempC_x10;      // temperature * 10 (fixed point, avoids float in the packet)
  uint8_t  humidityPct;
  int16_t  pressureRate_x100; // hPa/min * 100 (signed — can rise or fall)
  uint16_t gasRaw;         // raw ADC reading, calibration happens off-device
  uint8_t  motionEnergy;   // 0-255, scaled rolling accel-variance metric
  uint8_t  battery;        // 0-100
  uint8_t  riskState;      // 0 NORMAL / 1 WARNING / 2 CRITICAL (worker's own local computation, sent for cross-checking against backend fusion)
} TelemetryPayload;

// payload for MSG_EMERGENCY: TelemetryPayload fields PLUS:
typedef struct __attribute__((packed)) {
  TelemetryPayload base;
  uint8_t  hazardType;     // 0 GAS, 1 FALL, 2 SOS, 3 HEAT, 4 MULTI (see §7.4)
  uint8_t  severity;       // 1 WARNING / 2 CRITICAL / 3 SOS
} EmergencyPayload;
```

Notes an implementing agent must respect:
- `seq` increments per **originating** node, never reset by a relay — this is what lets any anchor detect and drop a duplicate it's already forwarded (§6.2).
- The gateway anchor decodes `MeshPacket` into JSON **before** it reaches the backend (§10) — nothing past the gateway needs to know this wire format.
- Fixed-point integers (`tempC_x10`, `pressureRate_x100`) are deliberate — floats in a packed struct sent over the air invite endianness/alignment bugs on some toolchains; fixed-point sidesteps it entirely and is cheap to decode on the backend.

---

## 5. Anchor Backbone Routing

Anchors run the same gradient-routing idea used in the general architecture doc, now applied only among fixed nodes (much more stable than applying it to mobile ones):

1. Every anchor broadcasts `MSG_ANCHOR_BEACON` every **2 s** (`config.h: BEACON_INTERVAL_MS`), containing its `positionM`, its own `hopCountToGateway`, and battery.
2. Each anchor keeps a neighbor table of other anchors it hears: `{anchorId, hopCountToGateway, lastSeenMs}`. It computes `myHopCount = min(neighbor.hopCountToGateway) + 1` and remembers `bestNextHop = argmin` (tie-break: most recently heard). The gateway anchor hardcodes `hopCountToGateway = 0`.
3. **Failure detection:** if `bestNextHop` hasn't beaconed in `3 × BEACON_INTERVAL_MS` (6 s, `config.h: ANCHOR_TIMEOUT_MS`), drop it from the table and recompute from whoever remains. This is the exact mechanism behind "power off Anchor 3, watch Anchor 2 and Anchor 4 route around it."
4. **Routine relay** (`MSG_ANCHOR_RELAY` wrapping a `TELEMETRY` payload, priority 0): unicast hop-by-hop via `bestNextHop`.
5. **Emergency relay** (priority 1): **broadcast** to all currently-known neighbor anchors, each of which forwards once (dedup via §6.2) and decrements `ttl` (`config.h: EMERGENCY_TTL`, default 10 — generous, this is a small backbone). This guarantees delivery via every simultaneously-live path, which is the point: an emergency should not be waiting on route recomputation.

---

## 6. Worker-to-Anchor Association

### 6.1 Choosing an anchor

The worker never actively "connects" to an anchor (ESP-NOW is connectionless) — it just decides which anchor to address its unicast packets to, based on what it's hearing:

- Maintain an EWMA-smoothed RSSI per heard anchor: `rssi_smoothed = 0.3 * rssi_new + 0.7 * rssi_smoothed` (`config.h: RSSI_EWMA_ALPHA`).
- `currentAnchor` only changes if a different anchor's smoothed RSSI exceeds the current one by more than `config.h: ANCHOR_SWITCH_MARGIN_DB` (default **6 dB**) for **two consecutive beacon periods**. Without this hysteresis, a worker standing roughly equidistant between two anchors will flap its target every beacon — visible on the dashboard as a worker "teleporting" between two positions, and a bad look in a demo.

### 6.2 Sequence-number dedup (also the replay defense named in the security section of `architecture-plan.md`)

Every node — anchor or worker — keeps a small ring buffer (`config.h: DEDUP_CACHE_SIZE`, default 32) of `{srcId, seq}` pairs it has already forwarded/processed, evicted oldest-first or after `config.h: DEDUP_TTL_MS` (default 8000 ms). A packet whose `{srcId, seq}` is already in the cache, or whose `seq` is at or below the last one accepted from that `srcId`, is dropped silently. This single mechanism does two jobs: stops flood storms from re-forwarding the same emergency packet forever, and rejects replayed/duplicated packets — implement it once, in `mesh.cpp`, shared by both roles.

### 6.3 Position estimate (this is a genuine capability, not a demo trick — GPS does not work underground)

Because anchors are installed at known, surveyed positions along the tunnel, a worker can estimate its own linear position without any location hardware:

```
if only one anchor heard within HEARING_FLOOR_DBM (config.h, default -85):
    position_estimate = thatAnchor.positionM        // coarse: "near Anchor K"
elif two anchors heard above the floor:
    w1 = pow(10, rssi1_smoothed / 20.0)
    w2 = pow(10, rssi2_smoothed / 20.0)
    position_estimate = (anchor1.positionM * w1 + anchor2.positionM * w2) / (w1 + w2)
else:
    position_estimate = last known value, flagged STALE after LOCATION_STALE_MS
```

This is a coarse, 1-D estimate, correct for the common case of a mostly-linear tunnel with anchors placed along it — it is **not** true trilateration and will be ambiguous exactly at a junction where the tunnel branches (two different corridors can be equidistant between the same anchor pair). If the deployment has branches, either place an anchor at every junction (so a worker near a branch always hears a junction-specific anchor most strongly) or add a `branchId` field to `BeaconPayload` and don't interpolate across a branch boundary. Say this explicitly to the team rather than letting the position estimate silently misrepresent a branch.

---

## 7. Risk Fusion (WORKER only) — this is the section that must not read like a copy of a threshold-based design

### 7.1 Adaptive baseline, not fixed thresholds

On boot, each worker runs a **calibration window** (`config.h: CALIBRATION_MS`, default 90 000 ms) during which it computes a running mean and variance for temperature, humidity, and gas raw value using Welford's online algorithm, then continues updating that baseline for the rest of runtime via an EWMA with a slow time constant (`config.h: BASELINE_TAU_MS`, default 600 000 ms / 10 min) — slow enough that a fast-onset hazard (seconds to low minutes) shows up as a clear deviation, but the baseline still tracks legitimate slow drift (e.g. the mine gradually warming toward end of shift) so the system doesn't need re-tuning every deployment.

**During calibration, the local state must display `CALIBRATING`, not `NORMAL`.** Showing a green "all clear" LED while the gas sensor heater hasn't even finished its first warm-up cycle (§8) is actively misleading and is exactly the kind of shortcut this spec is asking you not to take.

### 7.2 Signals actually fed into the fusion

| Signal | Derived as | Why not the raw value |
|---|---|---|
| `zTemp` | `(temp - baselineMean) / baselineStd` (std floored at `config.h: MIN_TEMP_STD`, default 0.5°C, to avoid division blowing up in a very stable environment) | Standard z-score against a live baseline, not a hardcoded "above 40°C" line that means something different in a naturally-hot mine versus a temperate one |
| `zHumidity` | Same z-score treatment | Same reasoning |
| `zPressureRate` | z-score of **dP/dt** (hPa per minute, computed from a rolling buffer of the last 3 BME280 readings), not of absolute pressure | Absolute pressure just reflects depth/weather and isn't itself hazardous; a **sudden rate of change** is what can indicate a structural event (a roof fall's pressure wave) or a ventilation failure. This channel does not exist in any of the threshold-based designs surveyed for the project's novelty analysis — treat it as a first-class hazard signal, not a logging afterthought |
| `zGas` | `max(0, (gasRaw - baselineMean) / baselineStd)` — **clipped at zero**, only positive deviation counts | A gas reading *below* baseline is not a hazard; don't let a symmetric z-score treat "slightly cleaner air than average" as equally suspicious as "slightly worse" |
| `motionEnergy` | Variance of accel-magnitude over a rolling 2 s window, scaled to 0–255 for the packet | Feeds fall-detection (§7.3) and is reported in telemetry, but is **not** part of the continuous z-score sum below — motion anomaly and fall are handled as a dedicated state machine, not folded into the ambient-risk score |

### 7.3 Fall / impact detection (context, not a bare threshold)

Maintain a calibrated "worn, at-rest" orientation from a complementary filter during the calibration window:
```
tiltAngle = 0.98 * (tiltAngle + gyroRate * dt) + 0.02 * accelDerivedAngle
```
Fall state machine (per-worker, runs every IMU sample, ~50 Hz recommended):
1. **Impact:** accel magnitude jerk exceeds `config.h: FALL_IMPACT_G` (default 3.0 g) within a `config.h: FALL_IMPACT_WINDOW_MS` (default 150 ms) window.
2. **Confirm:** after an impact, if `motionEnergy` stays below `config.h: FALL_STILLNESS_THRESHOLD` for `config.h: FALL_STILLNESS_MS` (default 2000 ms) **and** the tilt angle has deviated from the calibrated worn orientation by more than `config.h: FALL_TILT_DEG` (default 45°) → declare `hazardType = FALL`, `riskState = CRITICAL`.
3. If stillness doesn't hold (person gets back up) or tilt doesn't confirm (it was a jump, not a fall) → no state change, log the impact as a minor telemetry event only.

This directly targets the specific, named failure mode of accelerometer-threshold-only designs (can't distinguish a fall from a jump) rather than reproducing it.

### 7.4 Combined ambient risk score

```
R = sqrt( wG * zGas^2 + wT * zTemp^2 + wH * zHumidity^2 + wP * zPressureRate^2 )
```
Default weights in `config.h` (tune during field calibration, do not bury these in `risk_engine.cpp`): `wG = 0.40`, `wP = 0.25`, `wT = 0.20`, `wH = 0.15` — gas weighted highest because CO onset is the most acutely dangerous of the four ambient signals; pressure-rate weighted meaningfully because it's the one channel that can indicate a sudden structural/ventilation event rather than gradual drift.

**State transitions, with asymmetric hysteresis to prevent flicker:**
| Transition | Condition |
|---|---|
| → WARNING | `R > config.h: WARNING_ENTER` (default 2.5) |
| WARNING → CRITICAL | `R > config.h: CRITICAL_ENTER` (default 4.0) |
| CRITICAL → WARNING | `R < config.h: CRITICAL_EXIT` (default 3.2) — not the same as the entry threshold |
| WARNING → NORMAL | `R < config.h: WARNING_EXIT` (default 1.8) |

**Hard overrides — checked every loop iteration, independent of `R`, and always win:**
1. SOS button pressed → `riskState = SOS`, `hazardType = SOS`, latched (does not clear on its own; requires a long-press to acknowledge/reset locally, mirroring the "supervisor acknowledges" step in the user flow).
2. Fall confirmed (§7.3) → `CRITICAL`, `hazardType = FALL`.
3. **Absolute gas ceiling:** if raw gas ADC value corresponds to a concentration above `config.h: GAS_ABSOLUTE_CEILING_PPM` — a value the team must set from an actual mine-safety reference for CO (do not invent this number; it needs to reflect whatever exposure limit the deployment is meant to respect) — declare `CRITICAL` regardless of the adaptive baseline. This is deliberate belt-and-suspenders: the adaptive z-score catches relative anomalies you wouldn't think to hardcode; the absolute ceiling guarantees a known-dangerous concentration always triggers even if the baseline has drifted upward for some other reason.

### 7.5 Local feedback (must work with zero radio connectivity)

The WS2812 status LED and buzzer are driven directly from `riskState`, computed and updated locally regardless of whether any anchor is currently in range:
- `CALIBRATING` → slow blue pulse, silent.
- `NORMAL` → solid dim green, silent.
- `WARNING` → pulsing amber, short periodic beep.
- `CRITICAL` → pulsing red, continuous fast beep.
- `SOS` → solid red, distinct alarm tone (different pattern from CRITICAL so it's audibly distinguishable).

This local rendering must not depend on anything in `mesh.cpp` — a worker whose radio can't reach any anchor still needs to see and hear their own state.

---

## 8. MQ-7 Acquisition (the sensor most likely to be implemented lazily elsewhere — don't)

MQ-7 requires a **duty-cycled heater** per its datasheet: ~60 s at ~5V (burn-off / high-temperature phase) alternating with ~90 s at ~1.4V (low-temperature sensing phase); the analog reading is only meaningful near the end of the low-temperature phase.

**First, check which physical module the team has:**
- **Module with onboard heater-cycle driver** (common on breakout boards with a dedicated heater-control chip/timer already on the PCB): firmware only needs to read the ADC on a schedule synced to the module's known cycle — check the specific module's datasheet for its cycle timing and sync to it rather than assuming the 60/90 split above.
- **Bare MQ-7 element / module with an exposed heater pin:** firmware must drive the heater itself via a logic-level MOSFET on `config.h: MQ7_HEATER_PIN`:
  ```
  state HIGH_HEAT (60s):  heaterPin = PWM 100% duty  (≈5V across the heater through the MOSFET)
  state LOW_HEAT  (90s):  heaterPin = PWM ~28% duty   (approximates 1.4V average — verify against
                                                        the specific MOSFET/heater resistance on hand,
                                                        this duty value is a starting point, not a
                                                        guarantee)
  read ADC only in the last 5s of LOW_HEAT
  ```
  This state machine must be non-blocking (driven by `millis()` comparisons in the main loop or a hardware timer callback, never `delay(60000)`), because the mesh/heartbeat logic in `mesh.cpp` needs to keep running throughout.

Whichever path applies, **do not treat a raw `analogRead()` taken at an arbitrary moment as a valid gas reading** — this is the single most common shortcut in hobbyist MQ-7 code and it produces numbers that look plausible but aren't meaningfully calibrated to anything.

---

## 9. Main Loop Discipline

Both roles run a single non-blocking loop — no `delay()` anywhere in steady-state code (a `delay()` in `loop()` stalls ESP-NOW packet reception and heartbeat timing, which is exactly the kind of bug that makes the reroute demo flaky). Structure `loop()` as a set of independently-timed tasks checked every pass:

```
loop():
    now = millis()
    if now - lastBeacon   >= BEACON_INTERVAL_MS:    doBeacon(); lastBeacon = now      // ANCHOR
    if now - lastSample   >= SENSOR_SAMPLE_MS:       doSensorRead(); lastSample = now  // WORKER
    if now - lastFusion   >= FUSION_INTERVAL_MS:     doRiskFusion(); lastFusion = now  // WORKER
    if now - lastTelemetry>= TELEMETRY_INTERVAL_MS:  sendTelemetry(); lastTelemetry = now // WORKER
    checkSosButton()                                  // interrupt-flagged, handled every pass
    pruneStaleNeighbors(now)                          // both roles, §5/§6
    // ESP-NOW receive is callback-driven (esp_now_register_recv_cb), not polled here
```

Recommended defaults (`config.h`): `SENSOR_SAMPLE_MS = 200`, `FUSION_INTERVAL_MS = 500`, `TELEMETRY_INTERVAL_MS = 2000` (routine), emergency packets are sent **immediately** on state transition into CRITICAL/SOS, not on the next scheduled telemetry tick.

---

## 10. Gateway Bridge (GATEWAY-flagged anchor only)

The gateway anchor decodes every `MeshPacket` it (a) originates as relay traffic or (b) receives directly, and writes one JSON line per packet to USB serial at a fixed baud (`config.h: SERIAL_BAUD`, default 115200):

```json
{"msgType":"TELEMETRY","srcId":103,"srcRole":"WORKER","seq":4821,"hopCount":2,
 "tempC":24.3,"humidityPct":61,"pressureRateHpaMin":-0.02,"gasRaw":812,
 "motionEnergy":6,"battery":78,"riskState":"NORMAL","positionEstM":142.5,
 "rxAtMs":183820113}
```
Field names here are illustrative — the exact schema should be agreed with whoever implements the backend ingestion script (per `architecture-plan.md` §5), but the gateway's job is fixed regardless of exact field names: **decode the binary packet fully before it leaves the gateway**, so nothing downstream needs to understand `MeshPacket`.

---

## 11. Config Reference (every constant this spec has named, in one place)

| Constant | Default | Section |
|---|---|---|
| `WIFI_CHANNEL` | 6 | §2 |
| `BEACON_INTERVAL_MS` | 2000 | §5 |
| `ANCHOR_TIMEOUT_MS` | 6000 | §5 |
| `EMERGENCY_TTL` | 10 | §5 |
| `RSSI_EWMA_ALPHA` | 0.3 | §6.1 |
| `ANCHOR_SWITCH_MARGIN_DB` | 6 | §6.1 |
| `DEDUP_CACHE_SIZE` | 32 | §6.2 |
| `DEDUP_TTL_MS` | 8000 | §6.2 |
| `HEARING_FLOOR_DBM` | -85 | §6.3 |
| `LOCATION_STALE_MS` | 10000 | §6.3 |
| `CALIBRATION_MS` | 90000 | §7.1 |
| `BASELINE_TAU_MS` | 600000 | §7.1 |
| `MIN_TEMP_STD` | 0.5 | §7.2 |
| `FALL_IMPACT_G` | 3.0 | §7.3 |
| `FALL_IMPACT_WINDOW_MS` | 150 | §7.3 |
| `FALL_STILLNESS_MS` | 2000 | §7.3 |
| `FALL_TILT_DEG` | 45 | §7.3 |
| `wG / wP / wT / wH` | 0.40 / 0.25 / 0.20 / 0.15 | §7.4 |
| `WARNING_ENTER / EXIT` | 2.5 / 1.8 | §7.4 |
| `CRITICAL_ENTER / EXIT` | 4.0 / 3.2 | §7.4 |
| `GAS_ABSOLUTE_CEILING_PPM` | **not defaulted — team must set from a real reference** | §7.4 |
| `SENSOR_SAMPLE_MS` | 200 | §9 |
| `FUSION_INTERVAL_MS` | 500 | §9 |
| `TELEMETRY_INTERVAL_MS` | 2000 | §9 |
| `SERIAL_BAUD` | 115200 | §10 |

---

## 12. Acceptance Checklist (the implementing agent should self-verify these before calling the firmware done)

1. A single WORKER, powered on with **no anchor in range**, shows `CALIBRATING` then `NORMAL` on its own LED/buzzer, with no crash and no false CRITICAL, purely from local sensors.
2. Two ANCHORs powered on, a WORKER placed near Anchor 1: confirm (via serial log or the gateway's JSON stream) that telemetry routes through Anchor 1.
3. Move the WORKER (or attenuate signal) until Anchor 2 is clearly stronger: confirm the association switches once, not repeatedly, near the midpoint (validates the hysteresis in §6.1).
4. With three ANCHORs in a chain (1=gateway, 2, 3) and a WORKER associated with Anchor 3: power off Anchor 2. Within `ANCHOR_TIMEOUT_MS`, confirm Anchor 3's telemetry still reaches the gateway via an alternate path if one physically exists, or confirm the emergency-flood path succeeds even with no alternate path for an EMERGENCY-class packet specifically.
5. Trigger the SOS button: confirm an `EMERGENCY` packet is sent immediately (not on the next telemetry tick) and that local state changes to `SOS` even if radio is out of range.
6. Simulate a fall (a sharp shake meeting the impact threshold, followed by stillness): confirm `hazardType = FALL` fires; confirm a shake **without** subsequent stillness (e.g. continued movement) does **not** fire.
7. Confirm the gas channel's local state does not leave `CALIBRATING` before the MQ-7 heater cycle (§8) has completed at least one full low-heat phase.
8. Confirm no `delay()` calls exist anywhere reachable from `loop()` in either role's build.
9. Confirm every numeric threshold used in `risk_engine.cpp`, `mesh.cpp`, and `sensors.cpp` traces back to a named constant in `config.h` — grep for bare numeric literals in conditionals as a final check.

---

## 13. Open Items the Team Must Supply (do not guess these)

1. Exact number of anchors and their planned spacing/positions (`ANCHOR_POSITION_M` per unit) — depends on the specific mine tunnel being used for the demo.
2. `GAS_ABSOLUTE_CEILING_PPM` — must come from an actual CO exposure guideline the team is willing to cite, not an invented number.
3. Which MQ-7 module variant is physically on hand (onboard heater driver vs. bare element) — determines which branch of §8 applies.
4. Confirm the installed `arduino-esp32` core version across every team laptop before starting (§3) — pin it in a shared README so nobody discovers a mismatch mid-build.
5. Whether any anchor position corresponds to a tunnel junction/branch — affects whether §6.3's linear interpolation needs a `branchId` guard.

---

## 14. Explicit "Do Differently" Checklist

Compare against this before considering any module finished — each item names the shortcut to avoid and the section that replaces it:

- ❌ Fixed `if (gasValue > 500)` thresholds → ✅ adaptive baseline + z-score fusion (§7.1–7.4)
- ❌ Bare accelerometer-magnitude threshold for "fall" → ✅ impact + stillness + tilt confirmation state machine (§7.3)
- ❌ Treating absolute barometric pressure as a hazard signal → ✅ rate-of-change (dP/dt) as the actual signal (§7.2)
- ❌ `analogRead()` on the MQ-7 at an arbitrary moment → ✅ heater-cycle-synced reading (§8)
- ❌ GPS or a hardcoded "Zone 1/2/3" label for location → ✅ RSSI-interpolated position from surveyed anchor positions (§6.3)
- ❌ A flat mesh where every node (including mobile ones) relays for every other node → ✅ fixed-backbone-relays / mobile-leaves split (§0, §5, §6)
- ❌ `delay()`-based sensor or heater timing that stalls the radio loop → ✅ `millis()`-scheduled non-blocking tasks (§9)
- ❌ Silently showing "NORMAL" during sensor warm-up → ✅ explicit `CALIBRATING` state (§7.1, §7.5)
- ❌ Symmetric thresholding on gas deviation (equally suspicious of cleaner-than-baseline air) → ✅ one-sided clipped z-score (§7.2)
- ❌ A single entry/exit threshold per state (causes flicker at the boundary) → ✅ asymmetric hysteresis bands (§7.4)

---

## 15. References

- Bosch BME280 datasheet — combined humidity/pressure/temperature sensor: [bosch-sensortec.com](https://www.bosch-sensortec.com/media/boschsensortec/downloads/datasheets/bst-bme280-ds002.pdf)
- MQ-7 carbon monoxide sensor — datasheet, pinout, heater-cycle timing: [The Engineering Projects](https://www.theengineeringprojects.com/2024/02/mq-7-carbon-monoxide-sensor-datasheet-pinout-working.html), [SparkFun product page](https://www.sparkfun.com/carbon-monoxide-sensor-mq-7.html)
- Arduino-ESP32 ESP-NOW API reference (current, class-based) and the underlying ESP-IDF C API this spec targets: [docs.espressif.com — Arduino-ESP32 ESP-NOW](https://docs.espressif.com/projects/arduino-esp32/en/latest/api/espnow.html), [ESP-IDF ESP-NOW programming guide](https://docs.espressif.com/projects/esp-idf/en/stable/esp32/api-reference/network/esp_now.html)
- Espressif reference multi-node ESP-NOW example (current idioms): [ESP_NOW_Network.ino, espressif/arduino-esp32](https://github.com/espressif/arduino-esp32/blob/master/libraries/ESP_NOW/examples/ESP_NOW_Network/ESP_NOW_Network.ino)
- Underground mine gas monitoring context (why CO/CH4-specific sensing matters more than generic AQI): [Application of Gas Monitoring Sensors in Underground Coal Mines and Hazardous Areas — ResearchGate](https://www.researchgate.net/publication/292148696_Application_of_Gas_Monitoring_Sensors_in_Underground_Coal_Mines_and_Hazardous_Areas)

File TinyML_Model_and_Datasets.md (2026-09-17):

# TinyML in Bleep — Model, Training, and Datasets

This document explains how the tinyML anomaly-detection model works in Bleep's second worker/wall node pair (`firmware/worker_n/`, `firmware/wall_n/`), how it was trained, and — the part most worth reading carefully — where the training data actually came from and what that does and doesn't mean for the model's accuracy today.

## 1. Why tinyML instead of hand-picked thresholds

The original firmware (`worker_node.ino`) alarms on each sensor independently: if temperature crosses 40°C, or MQ-4 crosses a raw ADC value, that single reading alone latches a hazard. That works, but it can't express *combinations* — for example, a moderately elevated heart rate is completely normal for a worker who is moving, but the same heart rate at zero motion energy is a much stronger signal something is wrong. A bank of independent static thresholds can't see that relationship; each sensor is judged in isolation.

`worker_n.ino` layers a small **autoencoder** on top of the same sensors to catch exactly that kind of cross-sensor anomaly, without needing hand-labeled "this combination is dangerous" examples. It runs alongside the existing per-sensor thresholds (both are described in `dashboard_features.md`'s Feature 4 section) rather than replacing them.

## 2. Model architecture

- **Type:** a 1-hidden-layer autoencoder — `Linear → tanh → Linear → sigmoid`.
- **Shape:** 8 inputs → 6 hidden units → 8 outputs (reconstructing the same 8 inputs). That's roughly 8×6 + 6×8 = 96 weights plus biases — small enough to hand-implement as a couple of nested loops in C.
- **Inputs (in this fixed order, from `buildFeatureVector()` in `worker_n.ino`):**
  1. `temperatureC` (DHT11)
  2. `humidityPct` (DHT11)
  3. `airQualityRaw` (MQ-135, raw ADC)
  4. `combustibleGasRaw` (MQ-4, raw ADC)
  5. `heartRateBpm` (MAX30102)
  6. `spo2Pct` (MAX30102)
  7. `soilMoisturePct`
  8. `motionEnergy` (MPU6050-derived)

There is no `pressureHPa` in the feature set — the worker board has no BMP180 (that sensor only exists on `wall_n.ino`'s own local sensor set), so pressure is excluded entirely rather than sent as a dummy value.

**How inference works on-device:** each reading is min/max-normalized against a learned "normal" range per sensor, run through the tiny network, and compared against its own reconstruction. If the network — which has only ever learned to reconstruct *normal* combinations well — can't reconstruct a worker's current readings accurately, the reconstruction error spikes, and that error is the anomaly score. This is the standard unsupervised approach for constrained-hardware anomaly detection: no labeled "bad" examples are needed, only examples of normal operation.

**No ML framework on the device.** Inference is plain float matrix math (`tinyMLInfer()` in `worker_n.ino`) — no TensorFlow Lite Micro runtime, no third-party inference library. The only place any ML framework (`numpy`) is used at all is offline, during training on a laptop; the ESP32 only ever reads a generated header file (`tinyml_model.h`) full of float arrays and does the multiply-adds itself. This keeps the firmware's flash/RAM footprint small and avoids pinning the project to a specific TFLite Micro library version.

## 3. Training pipeline (`ml/train_tinyml_model.py`)

The trainer is a single, dependency-light Python script (`numpy` only) that:

1. Generates a training dataset (see §4 below — this is the important part).
2. Min/max-normalizes it using a fixed "plausible normal range" per sensor.
3. Trains the autoencoder for 3000 epochs of full-batch gradient descent on MSE reconstruction loss.
4. Computes the **anomaly threshold** as `mean(reconstruction error) + 3 × std(reconstruction error)` across the training set — i.e., a reading is flagged anomalous once its reconstruction error is a clear statistical outlier relative to what "normal" data reconstructs to.
5. Computes a **per-sensor threshold band** (`mean ± 3 standard deviations` of that sensor's *raw* training values), which is what the dashboard displays as each sensor's live ML-derived safe range, and what several of `worker_n.ino`'s own hazard thresholds (`TEMP_DANGER_C`, `MQ135_DANGER_RAW`, `HR_DANGER_HIGH_BPM`, etc.) are actually pulled from — see `TINYML_FEATURE_HIGH_THRESHOLD` / `TINYML_FEATURE_LOW_THRESHOLD` in the generated header.
6. Writes the trained weights, normalization ranges, anomaly threshold, and per-sensor bands into `tinyml_model.h` — generated **twice**, once into `firmware/worker_n/` and once into `firmware/wall_n/`, since the Arduino IDE only looks for a header inside the same folder as the `.ino` it's compiling.

Every per-sensor threshold band is additionally clamped to a **hard safety bound** (`HARD_SAFETY_BOUND` in the script) before being written out — e.g. the model can never report a "safe" ceiling above 40°C for temperature, or below 90% for SpO2, no matter what the training data says. This is defensive: the learned statistics can *tighten* a safety margin, but they can never loosen one past a physically-justified ceiling/floor. That guardrail matters a lot given what the training data actually is, covered next.

## 4. Where the training data comes from (read this part)

**There is no logged real-world sensor history for this project yet.** The dataset the model is trained on today is entirely **synthetic** — generated by `generate_synthetic_dataset()` in the training script, not collected from real workers or real mine conditions. Concretely:

- For each of the 8 sensors, a *plausible normal operating range* was defined by hand (`FEATURE_NORMAL_RANGE` in the script), based on:
  - the existing hand-picked danger thresholds already in `worker_node.ino` (e.g. "danger ≥ 40°C" implies "normal" tops out somewhere below that), and
  - typical sensor datasheet / operating ranges for each component (DHT11, MQ-135, MQ-4, MAX30102, generic soil moisture sensor).
- 6000 synthetic samples are drawn per training run, one row per sample, with each feature sampled from a truncated Gaussian centered in the middle of its normal range (standard deviation chosen so ~99.7% of samples land inside the defined range).
- A small amount of **deliberate cross-feature correlation** is injected — specifically, higher synthetic motion energy nudges heart rate up and SpO2 down slightly, mimicking mild exertion — because the entire point of using an autoencoder instead of independent thresholds is to let it learn correlations between sensors. Purely independent per-column noise wouldn't give it anything to learn there.
- One exception worth calling out: the MQ-4 (combustible gas) "normal" range was **widened from an original 100–1300 assumption to 100–3400** after real hardware testing across multiple independent sessions consistently showed this specific MQ-4 module's clean-air raw baseline sitting anywhere from ~2100 to ~3300 — not the much lower range originally assumed from the datasheet alone. That's the one place actual hardware behavior (not just datasheet numbers) has already fed back into the "synthetic" range definition, and it's a good example of why this needs to keep happening.

**What this means in practice:**
- The model has never seen a real worker's real vitals, a real mine's real ambient gas/temperature drift, or real sensor noise characteristics (beyond the one MQ-4 correction above). Its notion of "normal" is an informed guess, not a measurement.
- It is explicitly documented as a **placeholder appropriate for a hackathon-stage build**, not a claim of field-validated accuracy. The training script's own module docstring says so directly, and this document is repeating that on purpose so it doesn't get lost.
- The hard safety bounds (§3) exist specifically to contain the risk of that placeholder-ness — even if the synthetic data's assumptions are wrong in some direction, the model can't report a threshold outside the physically-justified danger boundary for that sensor.

## 5. Retraining on real data

The training script was written so that swapping synthetic data for real data is a small, contained change:

1. Log real STATUS packets from `worker_n.ino` (field names are documented in `wifi_json_protocol.md` / `sensora_telemetry.schema.json`) — from workers actually wearing the device under normal working conditions, ideally across a range of ambient temperature/humidity/gas conditions the site actually sees.
2. Replace `generate_synthetic_dataset()` in `ml/train_tinyml_model.py` with code that loads that logged CSV/JSON into the same 8-column layout (`FEATURE_NAMES` order).
3. Re-run `python3 ml/train_tinyml_model.py`. It overwrites both copies of `tinyml_model.h` with weights fit to the real data.

Nothing in `worker_n.ino` or `wall_n.ino` needs to change for this — the firmware only ever reads the generated header's arrays and constants, so it's agnostic to whether they came from synthetic or real training data. This is the intended next step before relying on this model's thresholds in an actual deployment, not an optional nice-to-have.

## 6. Summary

| | |
|---|---|
| Model | 8→6→8 autoencoder (tanh hidden, sigmoid output), ~96 weights |
| Training framework | numpy only, offline (laptop), full-batch gradient descent |
| On-device inference | Plain C float math, no ML runtime/library on the ESP32 |
| Training data | **Synthetic**, generated from hand-defined "plausible normal" ranges per sensor, informed by existing hardcoded thresholds + datasheets + limited real hardware calibration (MQ-4 only so far) |
| Real-world validation | None yet — explicitly flagged as a placeholder pending logged real sensor data |
| Safety guardrail | Learned thresholds are hard-clamped to physically-justified min/max bounds that training data can never loosen |

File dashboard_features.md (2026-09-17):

# Bleep — Dashboard Feature Tracker

Live artifact: **Sensora Watch** — https://claude.ai/artifact/MbasRczLbHmSZs2SWE92Aj

This file tracks what the dashboard actually does, feature by feature, matching the "implement on hardware, then wire into dashboard" workflow. Update this doc every time a new feature lands on the dashboard — don't let it drift from the live artifact.

**As of the latest publish, the artifact is a full command dashboard, not just the Feature 1 demo described below.** It now has seven tabbed sections — Overview, Workers, Alerts, Vitals & Gas, Mine Map, Reports, Admin — built for reference against MineGuard/MineGaurd-Pro/IoT-Safety-Monitoring-System's feature sets (worker registration, a 0–10 risk score, an alert history with acknowledge, per-sensor gauge bands against the tinyML thresholds, a schematic mine map with wall-node anchors, a generated master report, and admin-editable alarm thresholds). Everything below this point documents Feature 1/4 specifically (still accurate for the roster-card and hazard-latching behavior it describes) — it hasn't been rewritten section-by-section for the wider dashboard yet. Key points about the new build:

- **Data model** extends the schema below with a worker registry (`id`, `name`, `role`, `nodeId`) and a wall-node registry (`id`, `label`, `zone`, map `x`/`y`), both persisted to `localStorage` as a per-viewer convenience only — this is demo-grade persistence, not a real backend, and does not sync across devices or reach Claude.
- **Risk score** (0–10, shown fleet-wide as "Average Risk Score" and per-worker) is a dashboard-only indicator computed from proportional excess over each admin-editable threshold, plus inactivity and the tinyML anomaly score — it is not the same thing as the firmware's own latched pass/fail alarm logic, and changing a threshold in Admin never changes what the hardware itself alarms on.
- **Dummy data**: two demo workers (W1/W2) ship pre-registered against WALL1/WALL2 with a simulated STATUS ticker (default every 3s, editable in Admin) standing in for real ESP-NOW traffic, plus one seeded warning alert and one scripted demo distress ~9s after load so the page never opens looking empty. All of it is clearly a simulation, not real telemetry, and the "SIMULATED DATA" flag in the utility bar is clickable to pause/resume it.
- **Reports**: "Generate master report" builds a fleet-summary + per-worker + alert-history report in-page; "Print / Save as PDF" uses the browser print dialog (print-only CSS isolates the report sheet) and "Copy report text" uses the clipboard API with a manual-select textarea fallback — there is no file-download button, since the artifact sandbox blocks script-driven downloads.

---

## Status legend

- `LIVE` — implemented in the dashboard today, running on simulated data
- `WIRED` — implemented and confirmed working against a real ESP32 over WiFi
- `PLANNED` — designed (schema/protocol exists) but not yet in the dashboard UI

---

## Feature 1 — Fall & Inactivity Detection

**Status: `LIVE` (simulated data only — see "Known limitation" below)**

What's on screen:

- **Utility bar** — dark-navy top strip with Sensora branding, a live clock (updates every 1s), and a "SIMULATED DATA" flag so nobody mistakes demo output for a real feed.
- **Header** — page title, a scope chip reading "Feature 1 · Fall & Inactivity Detection" (keeps the demo honest about what's implemented vs. planned), and a wall-node link status indicator.
- **Stat tiles (4)** — Workers Monitored, Active Alerts, Network status, Last Update. Pulls from the same message stream every other panel uses, so nothing can go out of sync.
- **Alert banner** — appears only while at least one worker is in `FALL_SUSPECTED`; set in Atkinson Hyperlegible for maximum legibility on the highest-urgency element on the page. Disappears automatically once the event clears.
- **Worker roster** — one card per worker (currently W1). Each card shows: status pill (`OK` / `FALL SUSPECTED` / `OFFLINE`), current motion energy, ESP-NOW RSSI to the wall node, battery (renders "—" until battery reporting ships), last sequence number, and an inactivity-timer progress bar that fills toward the trigger threshold.
- **Event log** — scrollable, newest-first list of every STATUS/DISTRESS message received, each stamped with the dashboard's own arrival time (not the device's `millis()` — see protocol notes).
- **Demo & Testing Controls** — a dashed-border panel, visually separated from the "real" dashboard, with three buttons: Trigger fall (W1), Simulate movement (W1), Reset demo. Lets anyone demo the distress flow live without hardware in the room.

Data flow: every inbound message (simulated or real) goes through one function, `handleIncomingMessage(msg)`, which matches the wall-node JSON schema exactly (`schemaVersion`, `msgType`, `workerId`, `nodeId`, `seq`, `espnowRssi`, `timestamp`, `payload`). A worker is marked `OFFLINE` if no message has arrived in 15s. An ambient auto-tick every 3s keeps the page feeling alive between demo button presses.

**Known limitation:** the dashboard is published as a hosted HTTPS page. Browsers block an HTTPS page from fetching a plain-HTTP endpoint (mixed content) — so this hosted link cannot pull from the local Flask server described in `wifi_json_protocol.md` even on the same LAN. To go from `LIVE` to `WIRED`: run `sensora_watch.html` locally (not the hosted link) and add a `fetch('http://<laptop-ip>:5000/api/workers')` poll into `handleIncomingMessage()`. This is documented in more detail in `dashboard-feature1.md`.

---

## Feature 2 — Proximity / LiDAR-like Mapping

**Status: `PLANNED`**

Not yet on the dashboard. Build checklist scopes this down to a "proximity snapshot" (HC-SR04 distance + gyro-integrated yaw) rather than a full scan. Dashboard work for this hasn't started — expect a new panel (likely a simple radial/polar plot per worker) once the hardware side sends `distanceCm`/`yawDeg`. Protocol note: this is meant to extend the existing DISTRESS payload and bump `schemaVersion` to `2`, not create a parallel envelope.

## Feature 3 — Worker In/Out Counting

**Status: `PLANNED` — blocked on hardware (2 additional beam sensors needed at the mine entrance)**

Not yet on the dashboard. Once unblocked, expect a small counter tile (workers currently underground) added to the stat-tile row, likely fed by the wall node nearest the entrance rather than a change to the worker-worn payload.

## Feature 4 — Environmental & Vitals Hazard Sensing

**Status: `LIVE` (wired to real ESP32 hardware, same as Feature 1)**

Adds six more sensors to `worker_node.ino`, reusing the exact same latched-alarm pattern as fall detection and the SOS button (`triggerHazardAlert()`, a generalization of what used to be separate `triggerSOS()`/`triggerInactivityAlert()` implementations):

- **DHT11** — temperature & humidity. Sustained temperature ≥ 40°C latches a `HEAT_STRESS` alert.
- **BMP180** — barometric pressure, shown as a live reading (no alert threshold yet).
- **MQ-135** — toxic/air-quality gas (raw ADC). Sustained reading ≥ 4000 latches a `GAS_DANGER` / `TOXIC_GAS` alert.
- **MQ-4** — combustible gas / methane (raw ADC), the most safety-critical reading underground. Sustained reading ≥ 3000 latches `GAS_DANGER` / `COMBUSTIBLE_GAS`.
- **MAX30102** — heart rate and an approximate SpO2 estimate. Sustained HR ≥ 130 or ≤ 45 bpm, or SpO2 ≤ 90%, each latch their own alert.
- **Soil moisture** — floor-level water ingress / flooding proxy. Sustained reading ≥ 80% latches `WATER_INGRESS`.

All eight readings ride on every STATUS and DISTRESS packet regardless of which hazard (if any) is active, so the worker roster cards always show live gauges. Thresholds are starting values only — see `TEMP_DANGER_C` and friends near the top of `worker_node.ino`, and tune against real sensor behavior on-site. Every hazard requires `REQUIRED_HAZARD_SAMPLES` (5) consecutive breaching samples before latching, mirroring the existing impact-detection debounce, so a single noisy ADC read can't trigger a false alarm.

On the dashboard, each worker card now shows Temperature, Humidity, Pressure, Gas (MQ-135 / MQ-4), Heart rate / SpO2, and Soil moisture, with the value turned red once it crosses the same threshold the firmware alarms on — a supervisor can see a reading trending toward danger before it actually fires.

Not implemented from the reference projects this was scoped against (no matching hardware on this build): RFID/UWB/LoRa zone tracking, GPS/subsidence physics, an AI chat assistant, or LCD/haptic on-device displays.

## Other basic features (from the build checklist, not yet on the dashboard)

- Battery monitoring (schema field already reserved as `null`)
- Worker heartbeat / liveness beyond the 15s staleness check
- Wall-node watchdog / reboot detection
- Server-side persistent event log (currently in-memory in the demo Flask server)

---

## Design system reference (applies to all features, not just Feature 1)

- **Fonts:** Public Sans (headers/nav), Inter (body/UI), Roboto Mono with `tabular-nums` (all numeric/timestamp data), Atkinson Hyperlegible (alert banner only — highest-urgency text on the page).
- **Status colors (reserved, never decorative):** good `#0ca30c`, critical `#d03b3b`, offline `#8b93a0`. A neutral accent `#2a5f8a` is used for buttons/progress bars and never overlaps with status meaning.
- **Mode:** light mode only, by explicit design decision — no dark-theme block.
- New features should reuse these tokens rather than introducing new colors/fonts, so the roster/alert/event-log pattern stays consistent as Features 2 and 3 land.

---

*Keep this file in sync with the live artifact. When a feature moves from `LIVE` to `WIRED`, or a `PLANNED` feature ships, update its section here.*

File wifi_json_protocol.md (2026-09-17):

# Bleep — Wall Node → Dashboard WiFi/JSON Protocol

**Scope:** the wall node's ESP-NOW link to the worker is unchanged from the build checklist; this document is specifically the **wall node → dashboard** hop, now over WiFi instead of USB serial. It covers fall/inactivity detection plus the environmental and vitals hazard sensing added on top (DHT11, BMP180, MQ-135, MQ-4, MAX30102, soil moisture). The formal schema is `sensora_telemetry.schema.json` (same folder) — treat it as the source of truth; this doc explains how to use it.

---

## 1. Transport

The **wall node is the HTTP client**; the **dashboard laptop runs a small HTTP server**. The wall node POSTs one JSON object per event/update — this is push, not polling, so a DISTRESS message reaches the dashboard the instant it happens, with no delay waiting on a poll interval.

- Endpoint: `POST http://<dashboard-laptop-ip>:5000/api/telemetry`
- Header: `Content-Type: application/json`
- Body: one JSON object matching the schema (§2)
- Expected response: `200 OK` with a small JSON body — the wall node doesn't need to do anything with it, but checking the status code tells you whether the send actually worked

**Before writing any firmware for this:** put the wall node and the dashboard laptop on the **same WiFi network**, find the laptop's IP (`ipconfig` on Windows / `ifconfig` or `ip addr` on Mac/Linux — look for the WiFi adapter's address, e.g. `192.168.1.50`), and confirm you can `curl` that endpoint from another machine on the same network before you flash anything. A firewall blocking inbound connections on port 5000 is a common, easy-to-miss blocker — test this first.

---

## 2. Message shape

Every message has the same envelope; `payload` differs by `msgType`. Full field-by-field detail with descriptions is in `sensora_telemetry.schema.json` — this section just shows what it looks like on the wire.

**STATUS** (recommended addition — send every ~2s so the dashboard can show "worker OK" instead of going silent between events):
```json
{
  "schemaVersion": 1,
  "msgType": "STATUS",
  "workerId": "W1",
  "nodeId": "WALL1",
  "seq": 184,
  "espnowRssi": -58,
  "timestamp": 1928433,
  "payload": {
    "riskState": "OK",
    "motionEnergy": 14.2,
    "secondsSinceMotion": 2,
    "battery": null,
    "temperatureC": 27.4,
    "humidityPct": 58,
    "pressureHPa": 1008,
    "airQualityRaw": 612,
    "combustibleGasRaw": 340,
    "heartRateBpm": 78,
    "spo2Pct": 97,
    "soilMoisturePct": 12
  }
}
```

**DISTRESS** (required — sent immediately on any hazard trigger, not on the next scheduled tick; `hazardType`/`riskState` name which one fired — see `sensora_telemetry.schema.json` for the full enum):
```json
{
  "schemaVersion": 1,
  "msgType": "DISTRESS",
  "workerId": "W1",
  "nodeId": "WALL1",
  "seq": 185,
  "espnowRssi": -61,
  "timestamp": 1958712,
  "payload": {
    "hazardType": "FALL_SUSPECTED",
    "riskState": "FALL_SUSPECTED",
    "secondsInactive": 32.4,
    "motionEnergyAtTrigger": 0.3,
    "battery": null,
    "temperatureC": 27.4,
    "humidityPct": 58,
    "pressureHPa": 1008,
    "airQualityRaw": 612,
    "combustibleGasRaw": 340,
    "heartRateBpm": 78,
    "spo2Pct": 97,
    "soilMoisturePct": 12
  }
}
```

The same eight environmental/vitals fields ride on *every* message regardless of `hazardType` — they're a live snapshot from `worker_node.ino`'s continuous sensor loop, not something specific to the hazard that triggered a given DISTRESS. A worker in `FALL_SUSPECTED` still reports their gas/temperature/vitals readings at the moment of the fall, for instance.

Other `hazardType`/`riskState` values now in use: `SOS_BUTTON` / `SOS`, `INACTIVITY`, `HEAT_STRESS`, `TOXIC_GAS` / `GAS_DANGER`, `COMBUSTIBLE_GAS` / `GAS_DANGER`, `HIGH_HEART_RATE`, `LOW_HEART_RATE`, `LOW_SPO2`, `WATER_INGRESS`.

**Why `battery: null` instead of leaving the field out:** the dashboard code you write today should not need to change when battery monitoring gets added later — it should already know to expect a `battery` key and just render "—" for null. Same reasoning for `riskState` being treated as an open string rather than a hardcoded switch/enum on the dashboard side: you will add `WARNING`, `CRITICAL`, `SOS`, `OFFLINE` etc. as later features land, and the dashboard shouldn't need a code change every time.

**`timestamp` is `millis()`, not wall-clock time.** The wall node doesn't need NTP sync for this feature — that's real complexity for no real benefit at hackathon scale. Instead, have the **dashboard** stamp its own arrival time (`serverReceivedAt = now()`) the moment a message lands, and use that for anything you display, log, or put on the event timeline. Use `seq` (not `timestamp`) if you need to detect a dropped or out-of-order message.

---
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

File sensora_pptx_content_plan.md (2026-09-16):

# Sensora — Slide-by-Slide Content Plan for SENSORA_Template.pptx

This maps your actual project content onto the 17-slide template you uploaded. The template is a generic "SENSORA 2.0" pitch-deck skeleton with instructional placeholder text in every box — this plan replaces that placeholder text with your real content, slide by slide, in the same order and layout the template already uses.

Reference material pulled from the project: `architecture-plan.md`, `novelty-analysis.md`, `hardware-firmware-spec.md`, `feature-build-checklist.md`, `dashboard-features.md`, `wifi-json-protocol.md`.

---

## Slide 1 — Title / Cover

Template layout: big background gradient, deck title + subtitle.

- **Title:** Sensora — Intelligent Worker Safety & Resilient Emergency Response System
- **Subtitle:** Edge-computed risk detection and a self-healing ESP-NOW mesh that keeps a worker's safety state visible even when connectivity fails.
- Hackathon name / track, your team name, date — whatever the event's cover convention is.

Speaker note: this is the "elevator pitch in one breath" slide. Don't read it word for word — say it, then move.

---

## Slide 2 — Contents

Template layout: numbered list, 4 sections.

Keep the template's section structure as-is — it already matches a clean pitch arc:

1. Section 1 — Problem & Context
2. Section 2 — Solution & Technology
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

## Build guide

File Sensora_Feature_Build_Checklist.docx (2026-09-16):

SENSORA

Hardware Feature Build Checklist

Worker ESP32 + Wall ESP32 — features to implement one at a time, checked off as you go

Prepared 16 September 2026

Reality check — Feature 1 is a genuine ~2-hour job if your ESP-NOW link between the two boards already passes a test packet. Feature 2 (full LiDAR-style mapping) is not a 2-hour feature — MPU6050 has no magnetometer, so a gyro-only yaw estimate drifts within minutes, and a real point-cloud needs a servo to sweep the sensor; it's scoped down below to something genuinely buildable today. Feature 3 (in/out counting) needs hardware you don't have yet — a single sensor detects presence, not direction — so the real version is written for when you get it, with no shortcut pretending otherwise.

# Feature 1 — Fall / Inactivity Detection → Distress Signal

## Build this first. (~2 hours)

- Confirm the ESP-NOW link between the worker and wall ESP32 already sends/receives a basic test packet — fix this first if it doesn't, everything else depends on it
- Wire MPU6050 SDA/SCL to the worker ESP32's I²C pins (GPIO21/22), power from 3.3V
- Install Adafruit_MPU6050 + Adafruit_Sensor (or MPU6050_light) via Library Manager
- Write a throwaway sketch that prints accel X/Y/Z at ~10Hz to confirm wiring is good
- Every loop, compute a rolling “motion energy” value (e.g. sum of |accel − lastAccel| over the last second)
- Define INACTIVITY_THRESHOLD and INACTIVITY_DURATION_SEC as named constants at the top of the file, don't bury them in logic
- Run a millis()-based timer that resets to zero every time motion energy exceeds the threshold
- When the timer exceeds INACTIVITY_DURATION_SEC with no reset, set local state to FALL_SUSPECTED
- The instant FALL_SUSPECTED triggers, send an ESP-NOW packet to the wall node: {workerId, msgType=DISTRESS, timestamp}
- Also flash an LED / sound a buzzer on the worker board itself the instant it triggers — this must work even if the packet never arrives
- On the wall ESP32, register a receive callback that checks msgType==DISTRESS and immediately writes it as a JSON line over Serial
- On the laptop, run the simplest possible Python script that reads that serial line and prints it, so you can see the event land
- Temporarily set INACTIVITY_DURATION_SEC to ~10s while testing so you're not waiting a full minute per test; set it back before demoing

→ Dashboard, later: a worker card that flips red and shows “FALL SUSPECTED — [time]” the moment a DISTRESS message hits the server

# Feature 2 — Proximity Snapshot at the Moment of Distress

A scoped-down version of the LiDAR idea. A live sweeping map is a multi-session feature, not a 2-hour one — this version captures useful spatial context at the exact moment something goes wrong, which is the actual value of the idea, without requiring a servo or a magnetometer you don't have.

## Do this second. (~2 hours)

- Wire an HC-SR04 (or similar) ultrasonic sensor's TRIG/ECHO to two free GPIOs on the worker board
- Put a voltage divider (e.g. 1kΩ/2kΩ) on the ECHO line — HC-SR04's echo swings to 5V, above ESP32's 3.3V logic max
- Write a test function that pulses TRIG and times ECHO to get distance in cm; confirm it reads ~30cm when 30cm from a wall
- Reuse the MPU6050 already wired for Feature 1 to integrate a yaw estimate: yaw += gyroZ * dt, reset to 0 at boot
- Accept and label this yaw as “rough direction only” — it will drift over minutes with no magnetometer to correct it, don't present it as a compass heading
- On every FALL_SUSPECTED or SOS trigger, take one ultrasonic reading + the current yaw value and add them as extra fields on the DISTRESS packet (distanceCm, yawDeg)
- Test by triggering SOS at a known distance and orientation from a wall and checking the received numbers roughly match
- Explicitly defer continuous sweeping/point-cloud mapping — note it as a future feature needing a servo (SG90) to rotate the sensor, not part of today's build

→ Dashboard, later: a small directional arrow + distance readout on the active alert card, not a full map

# Feature 3 — Worker In/Out Counting at the Wall Node

## Needs new hardware before you can start.

- You can't build this with what you have right now — one ultrasonic/IR sensor tells you something passed, not which way; you need two beam sensors ~30–50cm apart at a single choke point to infer direction from which one triggers first
- Once you have two IR break-beam sensors (or a second ultrasonic), wire both to the wall ESP32's digital inputs
- Test each sensor independently — confirm it flips state when you wave a hand through it
- Direction logic: sensor A triggers before B within ~1.5s → IN; B before A → OUT
- Maintain a workerCount int on the wall node, increment on IN, decrement on OUT (floor at 0)
- Send workerCount to the server on every change, plus every ~30s as a heartbeat so the dashboard isn't stale
- Walk the gate both directions a few times and confirm the count tracks correctly; widen the timing window if a slow walk-through gets missed
- Don't try to fake this with RSSI/association timing from the existing mesh — direction is fundamentally ambiguous without two sensors, it's not worth the debugging time

# Other Basic Features Worth Adding

In rough priority order — each is small enough to slot into a spare hour once the three features above are working.

- SOS/panic button — one GPIO, immediate DISTRESS packet, always overrides every other state
- Local buzzer + status LED — shows NORMAL/WARNING/CRITICAL/SOS even with zero network, don't make this depend on the mesh working
- Battery voltage monitoring — ADC + voltage divider, send battery % every packet, flag LOW_BATTERY below a threshold
- Worker heartbeat packet — send a small “I'm alive” every N seconds so a worker can be marked OFFLINE (not silently NORMAL) if packets stop
- Wall node → server link watchdog — a distinct LED pattern on the wall ESP32 if its own serial/server link drops, so a backend disconnect is visible at the table
- Hardcoded WORKER_ID per device — so the server labels events by person, not raw MAC address
- Basic temperature/gas sensing (whatever you already have wired) — worker state shouldn't be motion-only
- Timestamped event log on the server (even a flat file or SQLite row per event) — this is what the dashboard's event timeline actually reads from

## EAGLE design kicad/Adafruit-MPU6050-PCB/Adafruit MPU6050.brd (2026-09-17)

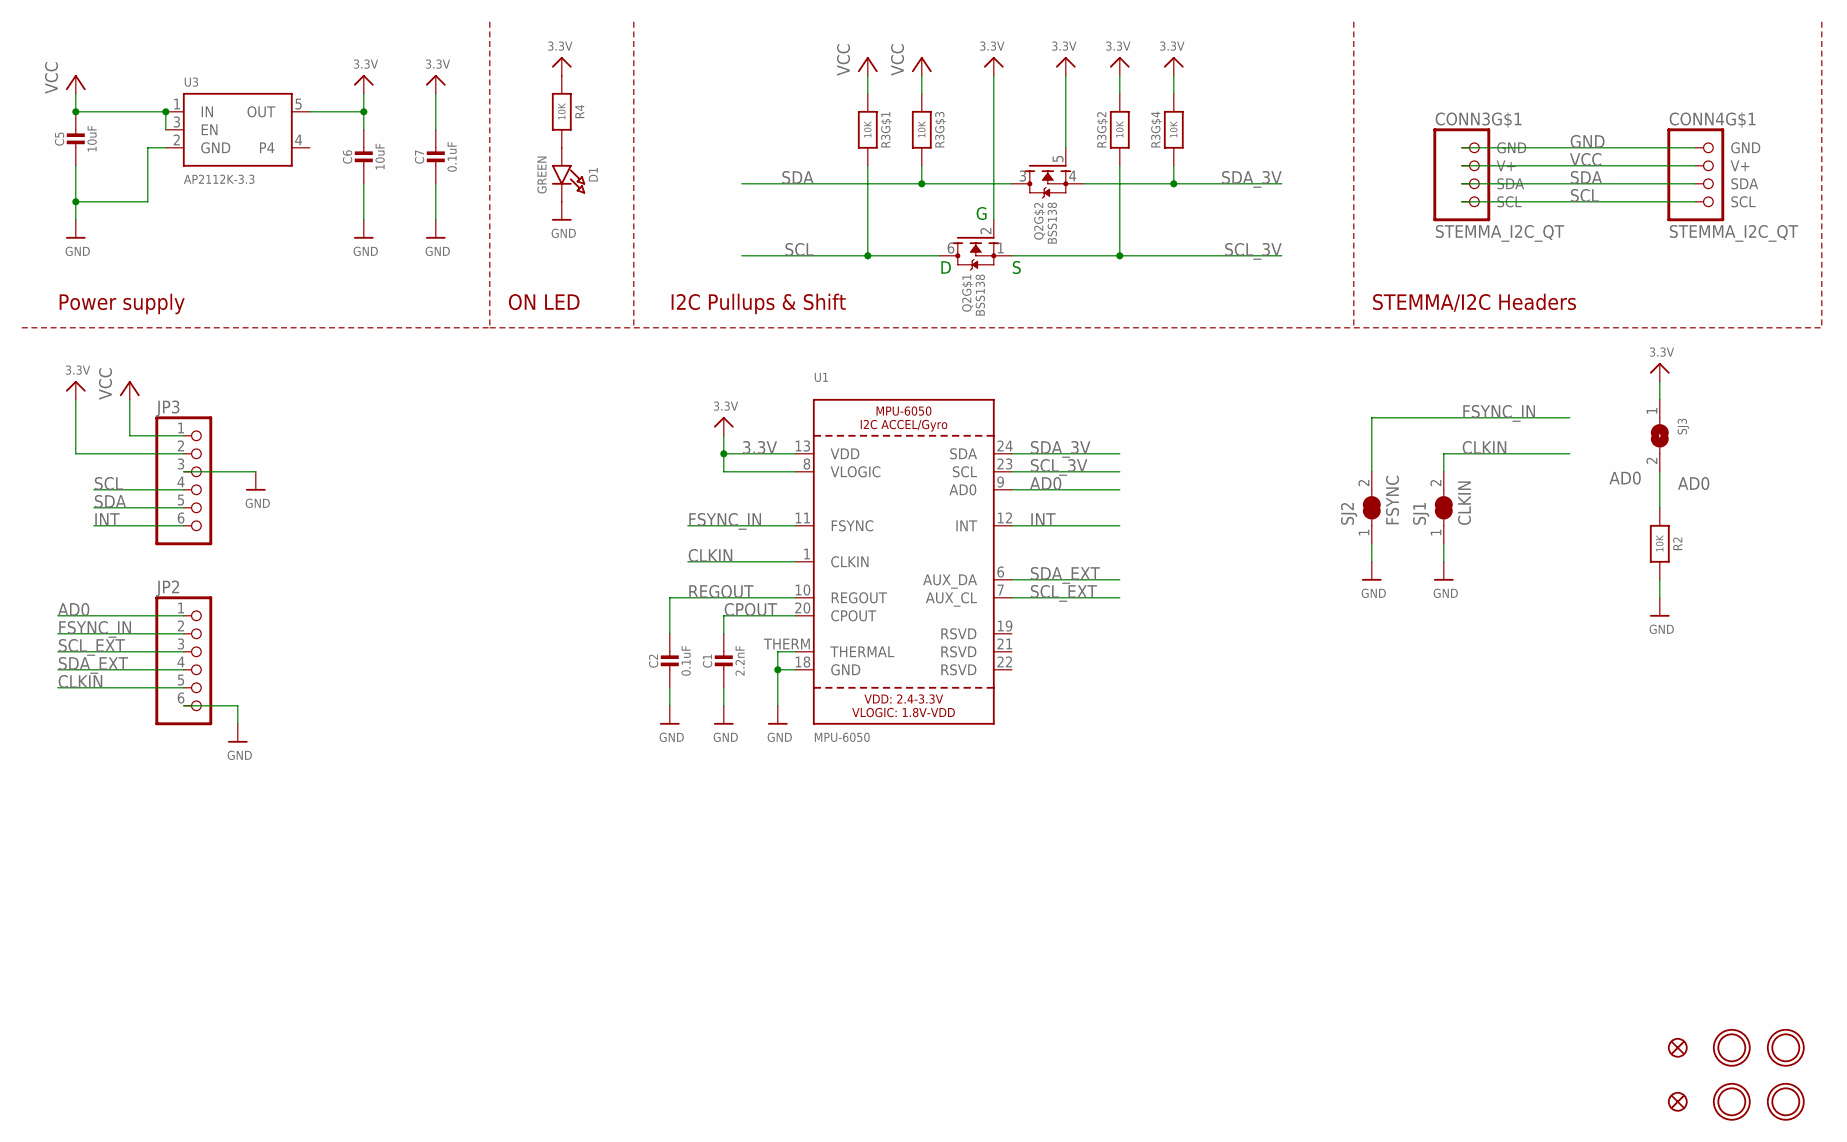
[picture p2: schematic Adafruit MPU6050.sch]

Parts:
C1: 2.2nF; 0603-NO
C2, C7: 0.1uF; 0603-NO
C5, C6: 10uF; 0805-NO
CONN3, CONN4: STEMMA_I2C_QT; JST_SH4
D1: GREEN; CHIPLED_0603_NOOUTLINE
FID3, FID4: FIDUCIAL_1MM
JP2: HEADER-1X6ROUND; 1X06_ROUND
JP3: HEADER-1X670MIL; 1X06_ROUND_70
Q2: BSS138; SOT363
R2, R4: 10K; 0603-NO
R3: 10K; RESPACK_4X0603
SJ1: CLKIN; SOLDERJUMPER_CLOSEDWIRE
SJ2: FSYNC; SOLDERJUMPER_CLOSEDWIRE
SJ3: SOLDERJUMPER; SOLDERJUMPER_ARROW_NOPASTE
U1: MPU-6050; QFN24_4MM_SMSC
U3: AP2112K-3.3; SOT23-5
U$39, U$40, U$42, U$43: MOUNTINGHOLE2.5; MOUNTINGHOLE_2.5_PLATED

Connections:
3.3V: C6.1, C7.1, JP3.2, Q2.2 (G), Q2.5 (G), R3.2 (1), R3.4 (1), R4.1, SJ3.1, U1.8 (VLOGIC), U1.13 (VDD), U3.5 (OUT)
AD0: JP2.1, R2.1, SJ3.2, U1.9 (AD0)
CLKIN: JP2.5, SJ1.2, U1.1 (CLKIN)
CPOUT: C1.1, U1.20 (CPOUT)
FSYNC_IN: JP2.2, SJ2.2, U1.11 (FSYNC)
GND: C1.2, C2.2, C5.2, C6.2, C7.2, CONN3.1 (GND), CONN4.1 (GND), D1.C, JP2.6, JP3.3, R2.2, SJ1.1, SJ2.1, U1.18 (GND), U1.THERM (THERMAL), U3.2 (GND)
INT: JP3.6, U1.12 (INT)
unnamed: D1.A, R4.2
REGOUT: C2.1, U1.10 (REGOUT)
SCL: CONN3.4 (SCL), CONN4.4 (SCL), JP3.4, Q2.6 (D), R3.8 (2)
SCL_3V: Q2.1 (S), R3.7 (2), U1.23 (SCL)
SCL_EXT: JP2.3, U1.7 (AUX_CL)
SDA: CONN3.3 (SDA), CONN4.3 (SDA), JP3.5, Q2.3 (D), R3.6 (2)
SDA_3V: Q2.4 (S), R3.5 (2), U1.24 (SDA)
SDA_EXT: JP2.4, U1.6 (AUX_DA)
VCC: C5.1, CONN3.2 (V+), CONN4.2 (V+), JP3.1, R3.1, R3.3 (1), U3.1 (IN), U3.3 (EN)

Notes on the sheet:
I2C Pullups & Shift
STEMMA/I2C Headers
ON LED
Power supply

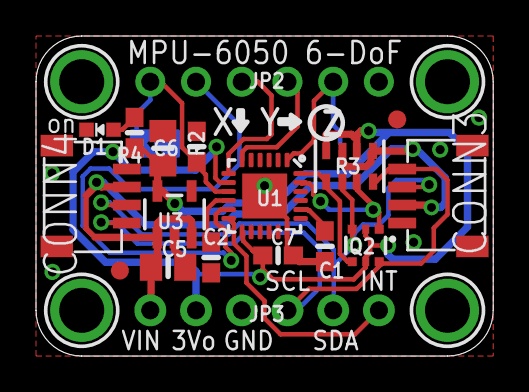
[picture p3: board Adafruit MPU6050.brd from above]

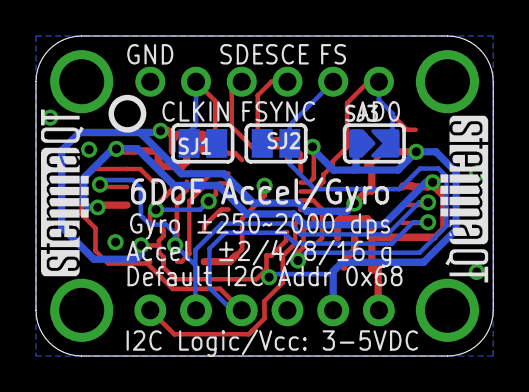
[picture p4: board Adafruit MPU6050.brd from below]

Board: 2 copper layers, 25.4 x 17.8 mm, 28 parts (6 on the bottom side), 16 nets.

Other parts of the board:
U$46: PCBFEAT-REV-040
U$47, U$48: STEMMAQT

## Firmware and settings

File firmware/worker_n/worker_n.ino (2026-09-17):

// Bleep -- Worker Node 2 (worker_n.ino)
//
// A second, independent worker/wall pair, wired per the "Complete
// worker-side map" and pairs with wall_n.ino. worker_node.ino and
// wall_node.ino are left untouched -- this is a parallel sketch, not
// a replacement.
//
// FALL DETECTION -- ported unchanged from a hand-tested standalone
// prototype ("WORKER SAFETY PROTOTYPE"): free-fall (acceleration
// drops below FREE_FALL_THRESHOLD) -> impact within IMPACT_WINDOW_MS
// (acceleration spikes above IMPACT_THRESHOLD) -> an UNCONDITIONAL
// FALL_CONFIRMATION_TIME_MS wait, after which the fall is confirmed
// regardless of movement during that wait. This file does not modify
// that logic or its thresholds at all -- see detectFall(). It only
// adds ESP-NOW/dashboard reporting and the environmental/vitals
// hazard layer around it.
//
// ALARM MODEL -- also ported from that prototype: a single sticky
// `alarmActive` flag drives the LED/buzzer. Once set (by a confirmed
// fall, the SOS button, or a latched environmental/vitals hazard) it
// stays on -- there is no button-press acknowledge/clear here,
// unlike an earlier version of this file. Clearing it means
// resetting the board. If you want an acknowledge button back,
// ask for it explicitly; it was intentionally left out to match the
// prototype's tested behavior exactly.
//
// DROPPED FROM AN EARLIER VERSION OF THIS FILE: the separate "no
// impact ever happened, just been motionless a long time" inactivity
// check. The prototype this was merged from has no such concept, and
// keeping it would have meant re-adding logic beyond what was asked
// for. Ask if you want it back.
//
// TINYML ANOMALY DETECTION -- unrelated to the fall logic above, this
// still supplies the ENVIRONMENTAL/VITALS hazard thresholds (heat,
// gas, heart rate, SpO2, water ingress) from a small trained
// autoencoder instead of hand-picked constants. See
// ml/train_tinyml_model.py for how tinyml_model.h was generated.
// Inference is plain float matrix math (no TensorFlow / TFLite Micro
// runtime on the device).
//
// SENSOR WIRING (from the "Complete worker-side map"):
//   MPU6050        3.3V/GND   SDA->21  SCL->22
//   MAX30102       3.3V/GND   SDA->21  SCL->22   (shares the I2C bus)
//   DHT11          3.3V/GND   DATA->27
//   MQ-135         5V*/GND    AO->34   (through a voltage divider -- ADC pins are 3.3V max)
//   MQ-4           5V*/GND    AO->35   (through a voltage divider)
//   Soil moisture  3.3/5V/GND AO->32
//   LED            --/GND     GPIO2
//   Buzzer         --/GND     GPIO4
//   SOS button     GPIO15 ---- BUTTON ---- 3.3V (INPUT_PULLDOWN: released=LOW, pressed=HIGH)
//
// No BMP180 on this board -- that sensor only exists on wall_n.ino's
// local sensor set. This worker packet still carries a pressureHPa
// field for wire-format compatibility with wall_n.ino's WorkerPacket
// struct, but it is always sent as NAN ("no reading"), and pressure
// is excluded from the tinyML feature set.
//
// Requires: ESP32 Arduino Core 3.x (wifi_tx_info_t send callback),
// Adafruit MPU6050, DHT sensor library, SparkFun MAX3010x library.

#include <WiFi.h>
#include <esp_now.h>
#include <esp_wifi.h>
#include <Wire.h>
#include <Adafruit_MPU6050.h>
#include <Adafruit_Sensor.h>
#include <DHT.h>
#include <MAX30105.h>
#include "heartRate.h"
#include <math.h>
#include "tinyml_model.h"

// ---------------------------------------------------------------------
// EDIT THESE
// ---------------------------------------------------------------------
const int WIFI_CHANNEL = 6; // must match wall_n.ino's WIFI_CHANNEL exactly

const char WORKER_ID[] = "W2";

// Wall Node 2's MAC -- read from wall_n.ino's own "Wall MAC Address:"
// boot log.
const uint8_t WALL_MAC[] = { 0x68, 0x25, 0xDD, 0x31, 0xB4, 0x60 };

// ---------------------------------------------------------------------
// PINS
// ---------------------------------------------------------------------
const int SDA_PIN = 21;
const int SCL_PIN = 22;

const int SOS_PIN = 15;
const unsigned long BUTTON_DEBOUNCE_MS = 50;

const int LED_PIN = 2;
const int BUZZER_PIN = 4;

const int DHT_PIN = 27;
#define DHT_TYPE DHT11

const int MQ135_PIN = 34;
const int MQ4_PIN = 35;
const int SOIL_PIN = 32;

// ============================================================
// FALL SETTINGS -- unchanged from the tested prototype. Do not
// rescale/retune these without re-testing on real hardware; they are
// not derived from the tinyML model on purpose (see file header).
// ============================================================
const float FREE_FALL_THRESHOLD = 5.0;
const float IMPACT_THRESHOLD = 15.0;
const unsigned long IMPACT_WINDOW_MS = 2000;
const unsigned long FALL_CONFIRMATION_TIME_MS = 10000; // 10 second confirmation, unconditional

// ============================================================
// STATUS INTERVAL -- how often environmental/vitals sensors are
// re-read, the tinyML hazard check runs, a routine STATUS packet is
// sent to wall_n.ino, and printStatus() runs. The tested prototype
// used 10000ms for this, but that made Serial output feel very slow
// to watch live -- 2000ms matches wifi_json_protocol.md's own "~2s"
// recommendation for dashboard responsiveness instead.
// ============================================================
const unsigned long STATUS_INTERVAL_MS = 2000;

// ============================================================
// ENVIRONMENTAL/VITALS HAZARD THRESHOLDS -- FROM THE TRAINED MODEL
// (unrelated to the fall settings above; see tinyml_model.h /
// ml/train_tinyml_model.py). Feature order (no pressure -- this
// board has no BMP180): 0 temperatureC, 1 humidityPct, 2
// airQualityRaw, 3 combustibleGasRaw, 4 heartRateBpm, 5 spo2Pct, 6
// soilMoisturePct, 7 motionEnergy.
// ============================================================
const float TEMP_DANGER_C        = TINYML_FEATURE_HIGH_THRESHOLD[0];
const float MQ135_DANGER_RAW     = TINYML_FEATURE_HIGH_THRESHOLD[2];
const float MQ4_DANGER_RAW       = TINYML_FEATURE_HIGH_THRESHOLD[3];
const float HR_DANGER_HIGH_BPM   = TINYML_FEATURE_HIGH_THRESHOLD[4];
const float HR_DANGER_LOW_BPM    = TINYML_FEATURE_LOW_THRESHOLD[4];
const float SPO2_DANGER_LOW_PCT  = TINYML_FEATURE_LOW_THRESHOLD[5];
const float SOIL_MOISTURE_DANGER_PCT = TINYML_FEATURE_HIGH_THRESHOLD[6];

// Hazard checks run once per STATUS_INTERVAL_MS (2s) tick. 2 samples
// means a hazard needs to stay above threshold for ~4s before it
// latches -- enough to reject a single noisy reading without being
// slow to react to a genuine, sustained hazard.
const int REQUIRED_HAZARD_SAMPLES = 2;

// ============================================================
// ESP-NOW PACKET -- MUST MATCH wall_n.ino EXACTLY
// ============================================================
typedef struct __attribute__((packed)) {
  char workerId[8];
  uint8_t msgType;              // 0 = STATUS, 1 = DISTRESS
  char riskState[16];
  char hazardType[16];
  float motionEnergy;
  float secondsSinceMotion;
  float motionEnergyAtTrigger;
  float temperatureC;
  float humidityPct;
  float pressureHPa;
  float airQualityRaw;
  float combustibleGasRaw;
  float heartRateBpm;
  float spo2Pct;
  float soilMoisturePct;
  float anomalyScore;
  uint32_t seq;
} WorkerPacket;

WorkerPacket packet;

// ============================================================
// SENSOR OBJECTS
// ============================================================
Adafruit_MPU6050 mpu;
DHT dht(DHT_PIN, DHT_TYPE);
MAX30105 particleSensor;
bool mpuFound = false;
bool max30102Found = false;

// ============================================================
// FALL STATE -- ported 1:1 from the tested prototype
// ============================================================
bool fallCandidate = false;
bool fallPending = false;
bool fallConfirmed = false;
unsigned long freeFallStartMs = 0;
unsigned long fallPendingStartMs = 0;

// ============================================================
// SOS + ALARM STATE
// ============================================================
bool sosPressed = false;
bool buttonLastRaw = LOW;
bool buttonStable = LOW;
unsigned long buttonLastChangeMs = 0;
bool alarmActive = false;

// currentRiskState/currentHazardType record WHICH condition raised
// alarmActive (fall, SOS, or a specific environmental/vitals hazard),
// purely for readable Serial output -- the ESP-NOW packet carries the
// same two strings to the dashboard.
char currentRiskState[16] = "OK";
char currentHazardType[16] = "";

// ============================================================
// MPU6050 READINGS
// ============================================================
float acceleration = 0.0; // magnitude, what detectFall() acts on -- matches the prototype's variable
float accelX = 0.0, accelY = 0.0, accelZ = 0.0;
float gyroX = 0.0, gyroY = 0.0, gyroZ = 0.0;
float previousX = 0.0, previousY = 0.0, previousZ = 0.0;

// motionEnergy is NOT part of the fall-detection logic (that's
// `acceleration` above, per the prototype) -- it exists purely as one
// of the 8 tinyML input features and for dashboard display.
float motionEnergy = 0.0;

// ============================================================
// ENVIRONMENTAL & VITALS READINGS
// ============================================================
float temperatureC = NAN;
float humidityPct = NAN;
float pressureHPa = NAN; // always NAN -- no BMP180 on this board
float airQualityRaw = 0;
float combustibleGasRaw = 0;
float soilMoisturePct = 0;
float heartRateBpm = 0;
float spo2Pct = 0;

int tempHazardSamples = 0;
int mq135HazardSamples = 0;
int mq4HazardSamples = 0;
int hrHighHazardSamples = 0;
int hrLowHazardSamples = 0;
int spo2HazardSamples = 0;
int soilHazardSamples = 0;
int mlAnomalyHazardSamples = 0;

float lastAnomalyScore = 0.0;

// ============================================================
// MAX30102 -- finger detection / heart rate / SpO2
// ============================================================
long lastIrValue = 0;
bool fingerDetected = false;
unsigned long totalBeatsDetected = 0; // diagnostic only

// MAX30105/MAX30102 clone modules vary a fair amount in baseline IR
// reading -- if printStatus() shows "finger=NO" with a clearly
// changed IR value when you touch the sensor, lower this; if it shows
// "finger=YES" with no finger present, raise it.
const long IR_FINGER_THRESHOLD = 20000;

const byte RATE_ARRAY_SIZE = 4;
long rateArray[RATE_ARRAY_SIZE];
byte rateSpot = 0;
unsigned long lastBeatMs = 0;

long spo2IrMin = 999999, spo2IrMax = 0;
long spo2RedMin = 999999, spo2RedMax = 0;

// ============================================================
// TIMERS
// ============================================================
unsigned long lastStatusTime = 0;
uint32_t sequenceNumber = 0;

// ============================================================
// ESP-NOW SEND CALLBACK -- fires asynchronously once the radio has
// actually attempted the transmission. Note this callback does NOT
// fire at all if esp_now_send() itself was rejected immediately (bad
// MAC, peer not added, etc) -- that case is printed separately, right
// where esp_now_send() is called, so a totally silent Serial Monitor
// on this board almost always means the peer/MAC setup, not this
// callback, is the problem (see checkWallMacConfigured() in setup()).
// ============================================================
uint32_t sendAttempts = 0;
uint32_t sendSuccesses = 0;
uint32_t sendFailures = 0;

void onDataSent(const wifi_tx_info_t *info, esp_now_send_status_t status) {
  sendAttempts++;
  if (status == ESP_NOW_SEND_SUCCESS) sendSuccesses++; else sendFailures++;
  Serial.println();
  Serial.println(status == ESP_NOW_SEND_SUCCESS
    ? "########## [ESP-NOW] SEND SUCCESS ##########"
    : "!!!!!!!!!! [ESP-NOW] SEND FAILED  !!!!!!!!!!");
  Serial.print("    totals: "); Serial.print(sendSuccesses); Serial.print(" ok / ");
  Serial.print(sendFailures); Serial.print(" failed / "); Serial.print(sendAttempts); Serial.println(" attempted");
}

// ============================================================
// TINYML INFERENCE -- 8 -> 6 (tanh) -> 8 (sigmoid) autoencoder.
// See tinyml_model.h / ml/train_tinyml_model.py.
// ============================================================
void buildFeatureVector(float out[TINYML_N_FEATURES]) {
  out[0] = temperatureC;
  out[1] = humidityPct;
  out[2] = airQualityRaw;
  out[3] = combustibleGasRaw;
  out[4] = heartRateBpm;
  out[5] = spo2Pct;
  out[6] = soilMoisturePct;
  out[7] = motionEnergy;
}

float tinyMLInfer(const float rawFeatures[TINYML_N_FEATURES], float perFeatureError[TINYML_N_FEATURES]) {
  float norm[TINYML_N_FEATURES];
  for (int i = 0; i < TINYML_N_FEATURES; i++) {
    float range = TINYML_FEATURE_MAX[i] - TINYML_FEATURE_MIN[i];
    float v = (rawFeatures[i] - TINYML_FEATURE_MIN[i]) / range;
    norm[i] = constrain(v, -0.5f, 1.5f);
  }

  float hidden[TINYML_HIDDEN_SIZE];
  for (int h = 0; h < TINYML_HIDDEN_SIZE; h++) {
    float z = TINYML_B1[h];
    for (int i = 0; i < TINYML_N_FEATURES; i++) {
      z += norm[i] * TINYML_W1[i][h];
    }
    hidden[h] = tanhf(z);
  }

  float totalError = 0.0;
  for (int i = 0; i < TINYML_N_FEATURES; i++) {
    float z = TINYML_B2[i];
    for (int h = 0; h < TINYML_HIDDEN_SIZE; h++) {
      z += hidden[h] * TINYML_W2[h][i];
    }
    float reconstructed = 1.0f / (1.0f + expf(-z));
    float err = reconstructed - norm[i];
    perFeatureError[i] = err * err;
    totalError += perFeatureError[i];
  }
  totalError /= TINYML_N_FEATURES;
  return totalError;
}

// ============================================================
// PRINT PACKET
// ============================================================
void printPacket() {
  Serial.println();
  Serial.println("========================================");
  Serial.println("       OUTGOING BLEEP PACKET (worker_n)");
  Serial.println("========================================");
  Serial.print("workerId: "); Serial.println(packet.workerId);
  Serial.print("msgType: "); Serial.println(packet.msgType);
  Serial.print("riskState: "); Serial.println(packet.riskState);
  Serial.print("hazardType: "); Serial.println(packet.hazardType);
  Serial.print("motionEnergy: "); Serial.println(packet.motionEnergy, 2);
  Serial.print("temperatureC: "); Serial.println(packet.temperatureC, 2);
  Serial.print("humidityPct: "); Serial.println(packet.humidityPct, 2);
  Serial.print("airQualityRaw (MQ-135): "); Serial.println(packet.airQualityRaw, 0);
  Serial.print("combustibleGasRaw (MQ-4): "); Serial.println(packet.combustibleGasRaw, 0);
  Serial.print("heartRateBpm: "); Serial.println(packet.heartRateBpm, 1);
  Serial.print("spo2Pct: "); Serial.println(packet.spo2Pct, 1);
  Serial.print("soilMoisturePct: "); Serial.println(packet.soilMoisturePct, 1);
  Serial.print("anomalyScore (tinyML): "); Serial.println(packet.anomalyScore, 5);
  Serial.print("seq: "); Serial.println(packet.seq);
  Serial.println("========================================");
}

void fillEnvironmentalFields(WorkerPacket &p) {
  p.temperatureC = temperatureC;
  p.humidityPct = humidityPct;
  p.pressureHPa = pressureHPa;
  p.airQualityRaw = airQualityRaw;
  p.combustibleGasRaw = combustibleGasRaw;
  p.heartRateBpm = heartRateBpm;
  p.spo2Pct = spo2Pct;
  p.soilMoisturePct = soilMoisturePct;
  p.anomalyScore = lastAnomalyScore;
}

// ============================================================
// SEND STATUS / DISTRESS PACKETS
// ============================================================

// Prints the IMMEDIATE, SYNCHRONOUS result of esp_now_send() itself
// -- this is separate from, and always prints even when, onDataSent()
// never fires at all (which happens whenever esp_now_send() rejects
// the packet outright, e.g. a bad/placeholder destination MAC). If
// Serial ever looks completely silent around a send, this is the line
// that explains why.
void printSendQueueResult(esp_err_t result, const char* label) {
  Serial.print("[ESP-NOW] esp_now_send(");
  Serial.print(label);
  Serial.print(") -> ");
  Serial.print(esp_err_to_name(result));
  Serial.println(result == ESP_OK
    ? "  (queued -- watch for SEND SUCCESS/FAILED next)"
    : "  (REJECTED IMMEDIATELY -- onDataSent() will NOT fire for this one)");
}

void sendStatusPacket() {
  memset(&packet, 0, sizeof(packet));
  strncpy(packet.workerId, WORKER_ID, sizeof(packet.workerId) - 1);
  packet.msgType = 0;
  strncpy(packet.riskState, "OK", sizeof(packet.riskState) - 1);
  packet.hazardType[0] = '\0';
  packet.motionEnergy = motionEnergy;
  packet.secondsSinceMotion = 0.0; // not tracked by this fall architecture -- see file header
  packet.motionEnergyAtTrigger = 0.0;
  fillEnvironmentalFields(packet);
  packet.seq = sequenceNumber++;

  Serial.println();
  Serial.println(">>> SENDING ROUTINE STATUS");
  printPacket();

  esp_err_t result = esp_now_send(WALL_MAC, (uint8_t *)&packet, sizeof(packet));
  printSendQueueResult(result, "STATUS");
}

// Shared by every distress source (fall, SOS, environmental/vitals
// hazard) -- builds and sends the DISTRESS packet, and records the
// reason in currentRiskState/currentHazardType for printStatus().
// Does NOT touch alarmActive/LED/buzzer -- callers set those
// themselves, since exactly how they do so differs (detectFall()'s
// own state machine vs. checkSOS()'s edge trigger vs. a hazard's
// debounce counter).
void sendDistressPacket(const char* riskState, const char* hazardType) {
  strncpy(currentRiskState, riskState, sizeof(currentRiskState) - 1);
  strncpy(currentHazardType, hazardType, sizeof(currentHazardType) - 1);

  memset(&packet, 0, sizeof(packet));
  strncpy(packet.workerId, WORKER_ID, sizeof(packet.workerId) - 1);
  packet.msgType = 1;
  strncpy(packet.riskState, riskState, sizeof(packet.riskState) - 1);
  strncpy(packet.hazardType, hazardType, sizeof(packet.hazardType) - 1);
  packet.motionEnergy = motionEnergy;
  packet.secondsSinceMotion = 0.0;
  packet.motionEnergyAtTrigger = motionEnergy;
  fillEnvironmentalFields(packet);
  packet.seq = sequenceNumber++;

  Serial.print(">>> IMMEDIATE "); Serial.print(hazardType); Serial.println(" DISTRESS PACKET");
  printPacket();

  esp_err_t result = esp_now_send(WALL_MAC, (uint8_t*)&packet, sizeof(packet));
  printSendQueueResult(result, hazardType);
}

// ============================================================
// READ MPU6050 -- called every loop() iteration, unconditionally
// (matches the prototype's own continuous-sampling loop). No 100ms
// gate here on purpose: a real impact shock lasts only a few
// milliseconds, and gating this to a slow tick was what caused fall
// detection to miss real drops in an earlier version of this file.
// ============================================================
void readMPU() {
  if (!mpuFound) { acceleration = 0; return; }

  sensors_event_t accel, gyro, temperature;
  mpu.getEvent(&accel, &gyro, &temperature);

  accelX = accel.acceleration.x;
  accelY = accel.acceleration.y;
  accelZ = accel.acceleration.z;
  gyroX = gyro.gyro.x;
  gyroY = gyro.gyro.y;
  gyroZ = gyro.gyro.z;

  acceleration = sqrt(accelX * accelX + accelY * accelY + accelZ * accelZ);

  // motionEnergy -- NOT used by detectFall() below, purely a tinyML
  // feature / dashboard value (see its declaration above).
  float dx = accelX - previousX;
  float dy = accelY - previousY;
  float dz = accelZ - previousZ;
  float currentChange = sqrt(dx * dx + dy * dy + dz * dz);
  motionEnergy = (motionEnergy * 0.8) + (currentChange * 0.2);
  previousX = accelX;
  previousY = accelY;
  previousZ = accelZ;
}
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
void loop() {
  readMPU();
  detectFall();
  checkSOS();
  updateHeartRate();
  updateAlarm();

  unsigned long now = millis();
  if (now - lastStatusTime >= STATUS_INTERVAL_MS) {
    lastStatusTime = now;

    readOtherSensors();
    checkEnvironmentalHazards();

    if (!alarmActive) sendStatusPacket();
    printStatus();
  }
}

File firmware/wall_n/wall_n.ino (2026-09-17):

// Bleep -- Wall Node 2 (wall_n.ino)
//
// Pairs with worker_n.ino. wall_node.ino and worker_node.ino are left
// untouched -- this is a second, independent pair, not a replacement.
//
// Two things this board does that the original wall_node.ino did not:
//   1. It has its OWN local sensors wired directly to it (see
//      "Node 2 -- ESP32 connections" pin map below) -- an MPU6050,
//      BMP180 and DHT11 for room/wall-mounted environmental readings,
//      plus an HC-SR04 ultrasonic sensor for distance/proximity (e.g.
//      a door, a hazard boundary, or clearance sensing). These are
//      read and printed to Serial on their own, independent of
//      anything coming over the radio.
//   2. It still hosts the SoftAP + ESP-NOW receiver + embedded
//      dashboard, exactly like wall_node.ino, but the SAME Serial
//      port now interleaves three kinds of output: this board's own
//      local sensor readings, and worker_n.ino's STATUS/DISTRESS
//      packets (which now include a tinyML anomalyScore field) --
//      all tagged so they're easy to tell apart in one Serial Monitor
//      window, and all merged into one JSON API for the dashboard.
//
// PIN MAP -- "Node 2 -- ESP32 connections":
//   MPU6050         VCC->3.3V  GND->GND  SDA->21  SCL->22
//   BMP180          VCC->3.3V  GND->GND  SDA->21  SCL->22  (shares the bus)
//   DHT11           VCC->3.3V  GND->GND  DATA->4
//   Ultrasonic      VCC->5V/VIN  GND->GND  TRIG->5  ECHO->18
//     HC-SR04
//
// Requires: ESP32 Arduino core >= 2.0.0 (esp_now_recv_info_t callback
// signature), ArduinoJson (v6.x), Adafruit MPU6050, Adafruit BMP085,
// DHT sensor library -- same library set as wall_node.ino plus the
// two used here for local sensing.

#include <WiFi.h>
#include <esp_now.h>
#include <WebServer.h>
#include <ArduinoJson.h>
#include <Wire.h>
#include <Adafruit_MPU6050.h>
#include <Adafruit_Sensor.h>
#include <Adafruit_BMP085.h>
#include <DHT.h>
#include "tinyml_model.h"

// ---------------------------------------------------------------------
// EDIT THESE
// ---------------------------------------------------------------------
const char* AP_SSID     = "Bleep-WallNode2";
const char* AP_PASSWORD = "bleepsafety";

// Must match worker_n.ino's WIFI_CHANNEL exactly.
const int WIFI_CHANNEL = 6;

const char* NODE_ID = "WALL2";

// worker_n.ino's MAC -- read off that board's own "Worker MAC: ..."
// boot log.
const uint8_t WORKER_MAC[] = { 0x00, 0x00, 0x00, 0x00, 0x00, 0x00 };

// ---------------------------------------------------------------------
// LOCAL SENSOR PIN MAP -- "Node 2 -- ESP32 connections"
// ---------------------------------------------------------------------
const int SDA_PIN = 21;
const int SCL_PIN = 22;

const int DHT_PIN = 4;
#define DHT_TYPE DHT11

const int ULTRASONIC_TRIG_PIN = 5;
const int ULTRASONIC_ECHO_PIN = 18;

const unsigned long LOCAL_SENSOR_INTERVAL_MS = 1000;   // MPU6050/BMP180/DHT11/ultrasonic
const unsigned long ULTRASONIC_TIMEOUT_US = 25000UL;   // ~4.3m round trip at 343 m/s, plenty for a room

// ---------------------------------------------------------------------
// ESP-NOW PACKET -- MUST MATCH worker_n.ino EXACTLY
// ---------------------------------------------------------------------
typedef struct __attribute__((packed)) {
  char workerId[8];
  uint8_t msgType;              // 0 = STATUS, 1 = DISTRESS
  char riskState[16];
  char hazardType[16];
  float motionEnergy;
  float secondsSinceMotion;
  float motionEnergyAtTrigger;
  float temperatureC;
  float humidityPct;
  float pressureHPa;
  float airQualityRaw;
  float combustibleGasRaw;
  float heartRateBpm;
  float spo2Pct;
  float soilMoisturePct;
  float anomalyScore;
  uint32_t seq;
} WorkerPacket;

WebServer server(80);

// Diagnostics for the ESP-NOW link specifically -- see onDataReceive()
// and the "still waiting" heartbeat in loop(). If packetsReceivedTotal
// stays at 0 forever, the packet isn't arriving at all (check
// WORKER_MAC in worker_n.ino, WIFI_CHANNEL match, and that both boards
// are actually powered).
uint32_t packetsReceivedTotal = 0;
unsigned long lastPacketReceivedMs = 0;

// ---------------------------------------------------------------------
// LOCAL SENSOR OBJECTS + LATEST READINGS
// ---------------------------------------------------------------------
Adafruit_MPU6050 mpu;
bool mpuFound = false;
Adafruit_BMP085 bmp;
bool bmpFound = false;
DHT dht(DHT_PIN, DHT_TYPE);

float localAccelX = 0, localAccelY = 0, localAccelZ = 0;
float localGyroX = 0, localGyroY = 0, localGyroZ = 0;
float localTemperatureC = NAN;      // from DHT11
float localHumidityPct = NAN;       // from DHT11
float localBmpTemperatureC = NAN;   // from BMP180 (separate sensor, kept distinct)
float localPressureHPa = NAN;       // from BMP180
float localDistanceCm = -1;         // from HC-SR04, -1 = no echo / out of range
unsigned long lastLocalSensorAtMs = 0;
unsigned long lastLocalSensorReadMs = 0; // millis() timestamp of the last successful read, for ageMs

// ---------------------------------------------------------------------
// VIBRATION DETECTION -- this wall node's own job for its MPU6050
// (worker_n.ino's MPU6050 does FALL detection instead; see that
// file). Sampled much faster than the 1s LOCAL_SENSOR_INTERVAL_MS
// above, same reasoning as worker_n.ino's fast impact-peak scan: a
// real shake/knock shows up as a brief spike that a 1Hz read could
// step right over.
// ---------------------------------------------------------------------
const unsigned long VIBRATION_SAMPLE_INTERVAL_MS = 20; // ~50 Hz
// Starting value only -- tune against your actual mount/surface, same
// caveat as every other hand-picked threshold in this project. A
// wall-mounted sensor picking up hand-shaking or nearby machinery
// will see much smaller accel deltas than worker_n.ino's wearable
// fall detector, hence the much lower threshold than that file's
// LOW_MOTION_THRESHOLD (4.0).
const float VIBRATION_THRESHOLD = 1.5;
const unsigned long VIBRATION_REPEAT_PRINT_MS = 300; // while confirmed vibrating, print at most this often

// Require the energy to stay above VIBRATION_THRESHOLD continuously
// for this long before calling it "vibrating" -- a single brief jolt
// (someone bumping the wall once, a door closing) should not print
// VIBRATING; sustained shaking/machinery for a couple of seconds
// should.
const unsigned long VIBRATION_CONFIRM_MS = 2000;

float vibPrevAccelX = 0, vibPrevAccelY = 0, vibPrevAccelZ = 0;
float vibrationEnergy = 0.0;
bool isVibrating = false;             // CONFIRMED (>= VIBRATION_CONFIRM_MS) vibration state
unsigned long vibrationStartMs = 0;   // 0 = not currently above threshold
unsigned long lastVibrationSampleMs = 0;
unsigned long lastVibrationPrintMs = 0;
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

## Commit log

2026-09-16 Add Bleep dashboard and project documentation
    Finished, standalone dashboard (index.html) covering the live Fall &
    Inactivity Detection feature plus illustrative Site Coverage and
    Device Security panels, alongside the editable design-canvas source
    and the existing hardware/firmware/protocol project docs.
2026-09-16 Wire the dashboard to real wall-node hardware
    Add the ESP32 wall-node firmware (ESP-NOW receive, RSSI capture,
    retrying DISTRESS / fire-and-forget STATUS POSTs matching the
    telemetry envelope), a Flask relay server that ingests that telemetry
    and serves the dashboard itself, and a live-polling mode in
    index.html that switches out of the simulated demo automatically once
    real hardware data starts arriving.
2026-09-16 Make every nav item, search bar, and card control interactive
    Sidebar nav now scrolls to the matching section (Dashboard, Site
    Coverage, Device Security) or opens a simulated preview modal for the
    sections that aren't built yet (Safety Exposure, Issues, Risk Score,
    Reports, Settings, Support). The search bar filters the worker
    roster, the avatar opens a real dropdown (Profile/Preferences/Sign
    out, closing itself when an item is picked), and every card's "View
    All"/"Details" control now opens a modal with dummy expanded data
    matching that card's theme. Demo buttons and live-hardware polling
    are unchanged.
2026-09-16 Add a wearable fall simulator for end-to-end testing without hardware
    Flashable to a second ESP32 — sends STATUS every 2s and a simulated
    DISTRESS roughly every 45s (auto-recovering 15s later), broadcasting
    over ESP-NOW so it can be picked up by the existing wall node
    firmware with no pairing step. Lets the wall node -> server -> dashboard
    pipeline be exercised without any accelerometer hardware.
2026-09-16 Add diagnostic logging to wall_node.ino for silent-failure debugging
    sendToDashboard() previously discarded the HTTP result for STATUS
    sends and gave no visibility into *why* a POST failed (bad URL,
    connection refused, timeout) — only a 3x-retry failure message on the
    DISTRESS path. It now logs the HTTP status code or client error on
    every send, and setup() echoes the configured DASHBOARD_URL and warns
    if it still looks like the placeholder IP, since that's the most
    common reason nothing reaches the dashboard.
    [wall_node.ino]
2026-09-16 Let wall_node.ino generate its own dummy fall data, no wearable needed
    Adds a SIMULATE_LOCAL_DATA mode that sends fake STATUS every 2s and a
    simulated DISTRESS roughly every 45s (auto-recovering 15s later),
    routed through the exact same sendStatus()/sendDistress() -> HTTP
    POST path a real ESP-NOW packet would use. Lets someone test the wall
    node -> server -> dashboard pipeline with a single ESP32 board before
    a second board or real wearable hardware exists. Flip the constant
    off once real hardware is sending real data.
    [wall_node.ino]
2026-09-16 Add real MPU6050 wearable firmware wired to ESP-NOW
    Integrates the provided MPU6050 + LED + buzzer fall-detection state
    machine (impact -> settling -> confirming -> fall confirmed) with
    ESP-NOW transmission matching wall_node.ino's WorkerPacket format
    exactly: a STATUS packet every 2s while healthy, and a DISTRESS
    packet (sent twice for redundancy) the moment a fall is confirmed.
    No changes to the fall-detection logic or thresholds themselves.
    [worker_node.ino]
2026-09-16 Merge detailed ESP-NOW receiver into wall_node.ino
    Adopts the richer packet-by-packet Serial logging (message type,
    risk/hazard state, motion energy, RSSI, a DISTRESS banner) and
    explicit worker-MAC peer registration from the new receiver sketch,
    while keeping the WiFi router connection and HTTP-to-dashboard
    forwarding that sketch didn't have — without those, ESP-NOW packets
    would print locally but never reach the website. Also points
    WIFI_SSID/WIFI_PASSWORD at the same network worker_node.ino uses.
    [wall_node.ino]
2026-09-16 Rewrite worker_node.ino with the refined MPU6050 state machine
    Adopts the updated fall-detection logic (simplified 4-state machine,
    double-trigger guard, global reused packet struct) and ESP-NOW
    unicast-to-WALL_MAC addressing, while restoring the WiFi.begin()
    router connection the new code dropped -- without it the worker never
    lands on the wall node's WiFi channel and ESP-NOW frames go nowhere.
    Also fixes the send callback to the Core 3.x wifi_tx_info_t signature
    in both this file and wearable_fall_simulator.ino, which wouldn't
    have compiled on Core 3.x before.
    [worker_node.ino]
2026-09-16 Strip the dashboard down to only real hardware data
    Removes everything that was never backed by wall_node.ino/
    worker_node.ino telemetry: the fabricated Site Coverage and Device
    Security sections, the static W2/W3 placeholder roster cards, the
    Demo & Testing Controls (client-side fake data injection), and every
    dummy-data modal. What remains is driven entirely by polling
    /api/workers and /api/events -- an honest "waiting for data" state
    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
2026-09-16 Add wall-node heartbeat and a "Wall Nodes Online" dashboard tile
    wall_node.ino now POSTs a lightweight heartbeat every 5s to a new
    /api/node-heartbeat endpoint, independent of whatever worker
    telemetry it's relaying -- this is what lets the dashboard tell "wall
    node is alive but quiet" apart from "wall node is dead," which
    worker-traffic-derived status alone couldn't do. The heartbeat URL is
    derived from DASHBOARD_URL at runtime so there's still only one IP to
    edit.
    server/app.py tracks node presence (from both heartbeats and ordinary
    telemetry) and exposes it via GET /api/nodes.
    index.html adds a "Wall Nodes Online" stat tile and reworks the
    connection-status logic to check real node hear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
    [wall_node.ino, worker_node.ino]
2026-09-16 Make worker_node.ino ESP-NOW-only, no WiFi/internet connection
    Replaces WiFi.begin() + router credentials with esp_wifi_set_channel(),
    which pins the radio to the wall node's channel directly without ever
    associating to an access point, requesting an IP, or touching the
    internet. The worker now only ever talks to WALL_MAC over ESP-NOW.
    Trade-off: since the worker can no longer ask the router what channel
    it's on, WIFI_CHANNEL must be kept in sync by hand with whatever
    wall_node.ino reports at boot ("Connected. WiFi channel: N").
    [worker_node.ino]
2026-09-16 Switch to a true peer-to-peer ESP32 network -- no router/hotspot
    wall_node.ino now hosts its own SoftAP (WiFi.softAP, no WiFi.begin())
    so a laptop can connect to it directly with no router, hotspot, or
    internet involved anywhere in the path. It also absorbs the server
    role entirely: an in-memory store replaces the Flask relay, and the
    board serves both the dashboard and its JSON API itself over the
    same SoftAP via WebServer.h. HTTPClient/DASHBOARD_URL/heartbeat-POST
    are gone -- there's no laptop-side server left to POST to.
    Because there's no internet, there's no NTP, so the wall node has no
    real wall-clock. Every API response now reports "ageMs" (elapsed
    time, computed fresh per request fr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
    [wall_node.ino, worker_node.ino]
2026-09-16 Add a working SOS button and fix the post-fall dead end
    worker_node.ino had no button-reading code at all, so a wired SOS
    button could never have reported anything -- pollButton() (debounced,
    polled every loop iteration) now reads it. Pressing it during normal
    monitoring raises an immediate manual SOS distress packet
    (riskState "SOS", distinct from an automatic "FALL_SUSPECTED"
    detection). Pressing it while FALL_CONFIRMED is latched acknowledges
    and clears the alarm, then sends an updated STATUS immediately --
    previously there was no way to ever see an update after a fall, since
    routine STATUS sending is deliberately paused in that state.
    Also fixes both dashboards (index.html and wall_node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
    [wall_node.ino, worker_node.ino]
2026-09-16 Fix the inactivity timer and add real pure-inactivity detection
    secondsSinceMotion was computed from impactTime (time of the last
    hard jolt >= IMPACT_THRESHOLD), which only ever updates on a real
    impact -- during ordinary handling it never resets, so the reported
    inactivity duration climbed forever regardless of actual activity.
    Added lastMotionTime, updated every sample whenever motionEnergy
    exceeds LOW_MOTION_THRESHOLD, and switched every "seconds since
    motion" calculation (STATUS, fall, SOS) to use it instead.
    Also added a standalone inactivity trigger: previously the 20s
    inactivity check only ever ran after an impact already happened, so
    "just leaving it inactive" with no jolt did nothi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
    [wall_node.ino, worker_node.ino]
2026-09-17 Add tinyML worker/wall node pair, PCB reference, and rebranded dashboard
    Adds a second, independent worker/wall ESP32 pair (wall_n/worker_n) that
    layers a trained autoencoder anomaly model onto the environmental/vitals
    hazard thresholds plus local wall-node sensing, the Python trainer that
    generates its tinyml_model.h, a vendored Adafruit MPU6050 PCB reference
    design, and two dashboard artifacts (sensora_watch.html, bleep_watch.html)
    documenting the command-dashboard build and its live-hardware Live Data
    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
    [Adafruit MPU6050.brd, Adafruit MPU6050.kicad_sch, Adafruit MPU6050.sch]
2026-09-17 Redesign Bleep Command dashboard with sidebar UI and interactive 3D mine map
    Replaces the tab-bar layout with a sidebar nav, overhauls the mine map into
    a real interactive 3D scene (vendored three.js + OrbitControls, no CDN) with
    RSSI-estimated worker positioning and a pulsing SOS/fall beacon, and
    redesigns Live Monitoring into per-node worker blocks with a proximity
    count and an urgent fall-detected popup for live hardware workers.
    Also fixes a worker_n.ino compile error (usingDummyVitals used before its
    declaration), disables non-fall/SOS alarm triggers per hazard-scope request,
    and adds TinyML_Model_and_Datasets.md documenting the autoencoder model,
    training pipeline, and the synthetic-d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
    [worker_n.ino]

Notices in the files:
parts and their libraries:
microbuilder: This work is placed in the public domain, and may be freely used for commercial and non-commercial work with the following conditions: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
